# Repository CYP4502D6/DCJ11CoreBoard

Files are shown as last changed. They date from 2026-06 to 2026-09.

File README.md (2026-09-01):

# DEC DCJ-11 PDP-11 Replication Project

Hardware specification and implementation status for the validated v1.3 hardware revision.

## Hardware Specifications 

* **CPU:** DEC DCJ-11
* **FPGA:** Intel/Altera Cyclone IV EP4CE15F23C8N
* **SRAM:** 2× Cypress Semiconductor CY62167EV30LL-45/55ZXI
* **FPGA Configuration Flash:** Winbond W25Q64JVSSIQ
* **UART Interface:** WCH CH340N
* **Bus Transceivers:** 5× Texas Instruments SN74CB3T3245
* **LED Controllers:** 2× Awinic AW21024
* **Status Indicators:** 
    * 8× Onboard direct LEDs (RUN, HALT, ABORT, FETCH, READ, WRITE, IO_SPACE)
    * 16-bit Data bus and 22-bit Address bus LEDs (Driven via AW21024 controllers)
* **MCU & Ethernet Subsystem for DEQNA (v1.3 Integrated):**
    * RP2040 MCU
    * Reserved expansion header for Wiznet W5500 SPI Ethernet PHY module
---

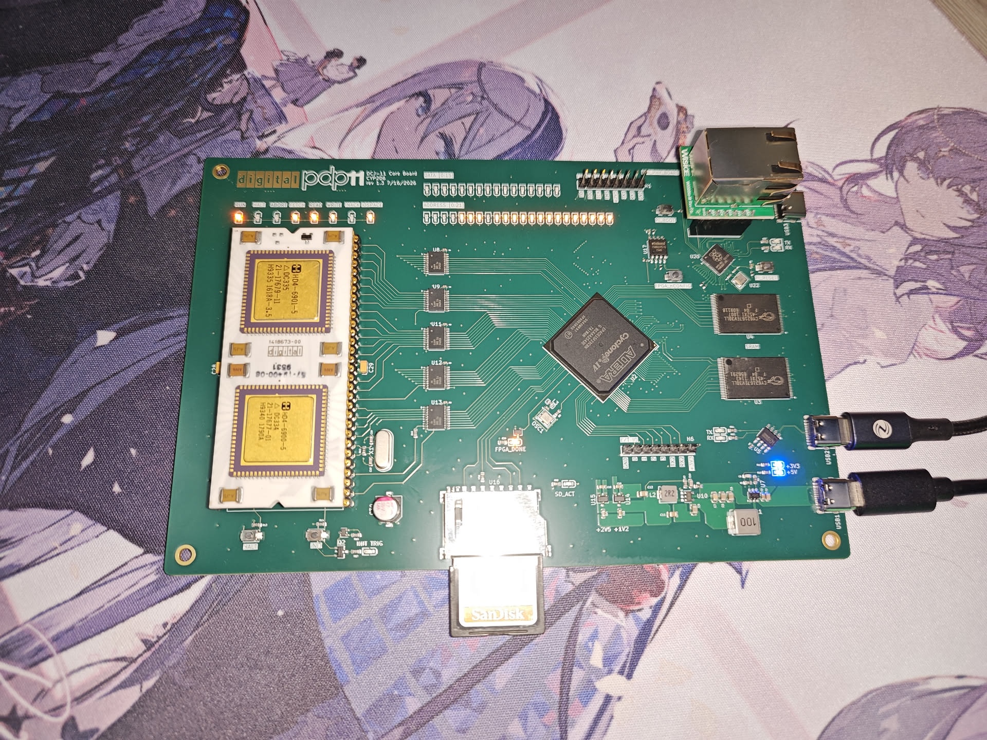
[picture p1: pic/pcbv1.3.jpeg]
Assembled PCB v1.3


## Implementation and Validation Status

### Full 2.11 BSD Unix Implementation for v1.3 Board
System intergration for running full multi-user mode 2.11 BSD Unix via RP06 disk.
* **Functionality:**
  * Power-on configuration and pre-loading 45Boot bootloader into SRAM starting at octal address `2000`.
  * Full 4 MiB physical SRAM memory mapping exploiting the 22-bit address space.
  * DEC KL11 compatible UART console interface for system terminal I/O.
  * DEC KW11 line-frequency real-time clock generator.
  * DMA-capable DEC RH11 disk controller emulation, enabling direct block transfers for 2.11 BSD RP06 disk images.
* **Resources & Demonstration:**
  * Video Demonstration: https://www.bilibili.com/video/BV1oagP6AEpL/

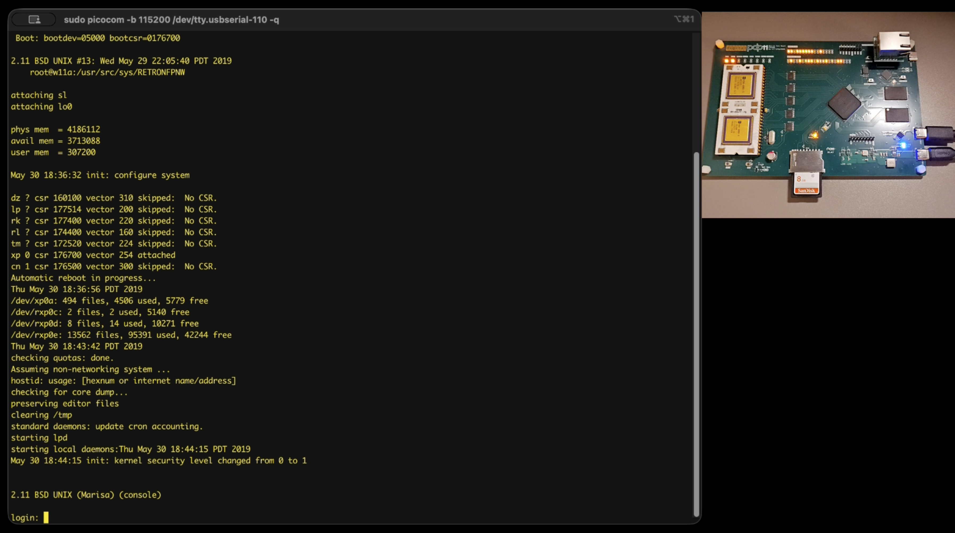
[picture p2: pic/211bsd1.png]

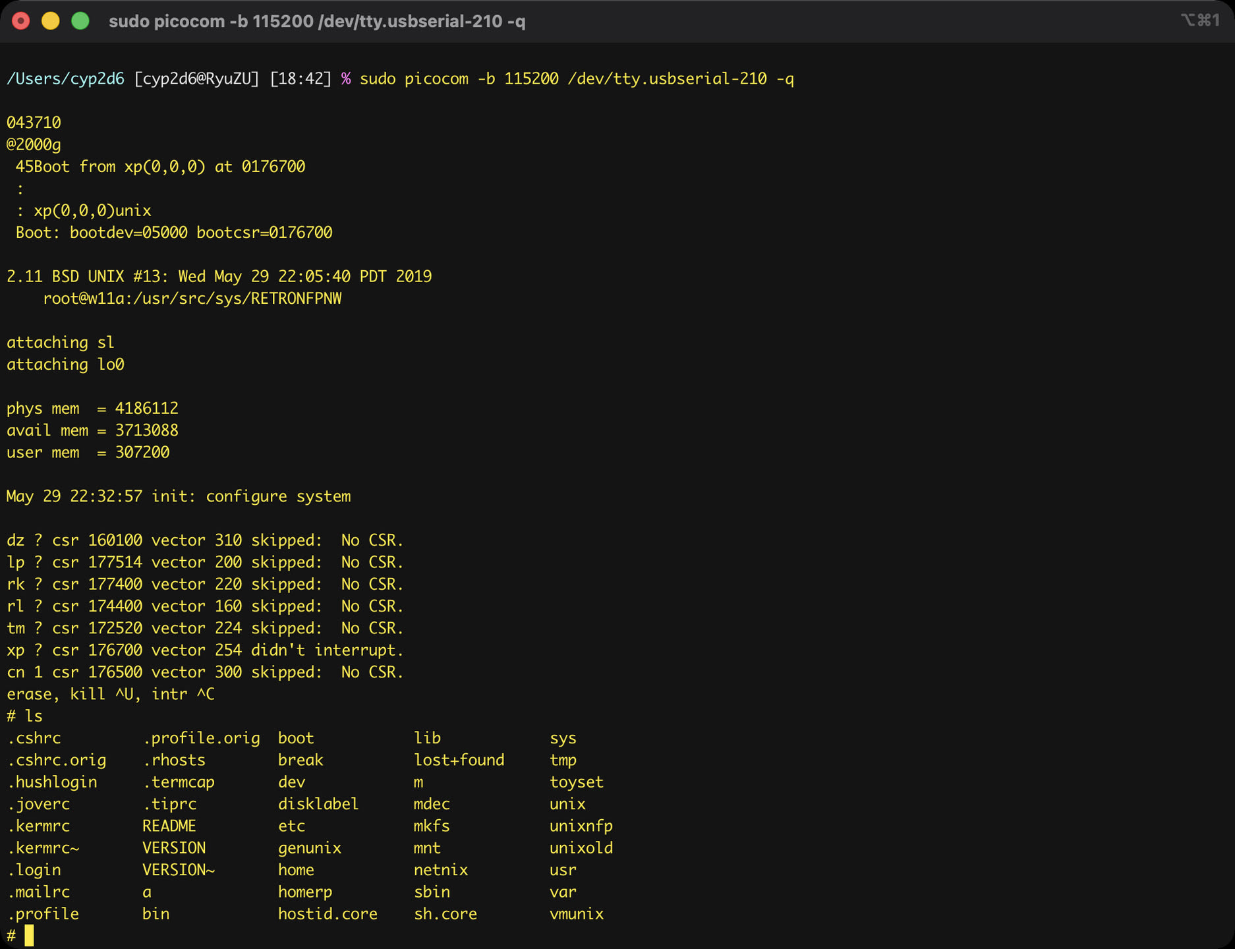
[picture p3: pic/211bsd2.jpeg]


### Board-Level Hardware Bringup for v1.2 Board
Initial board-level hardware verification using Verilog to validate subsystem integrity.
* **Scope:** Individual validation of AW21024 controllers, SRAM interface, onboard status LEDs, and UART peripheral lines.

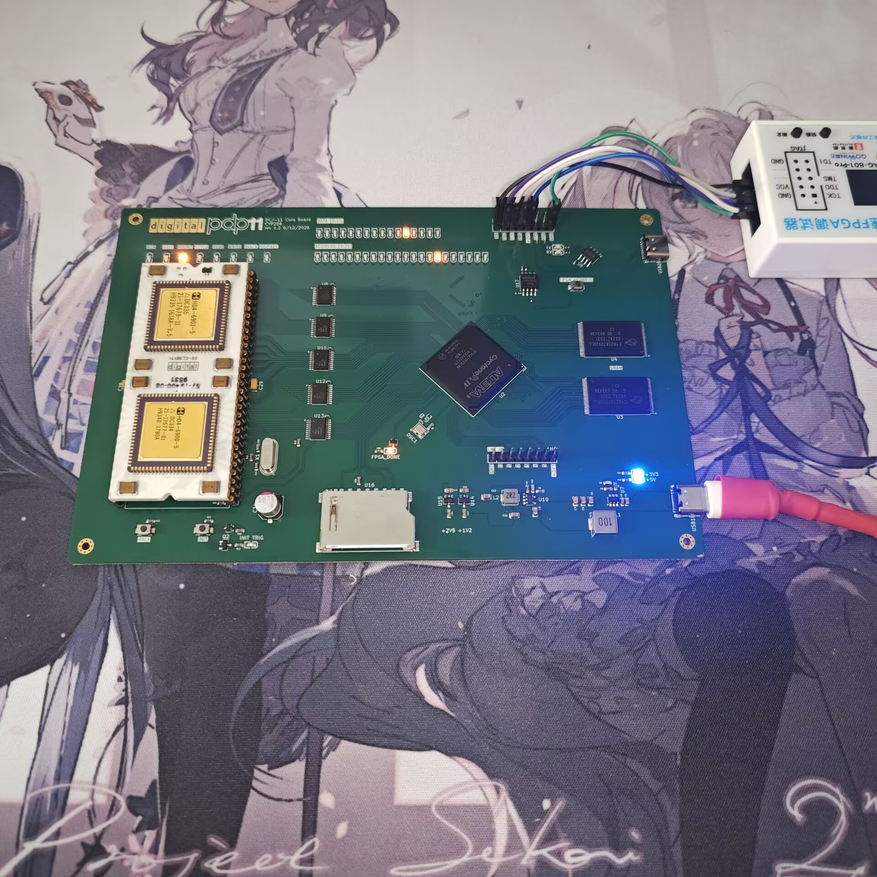
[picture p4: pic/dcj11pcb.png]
Board Top

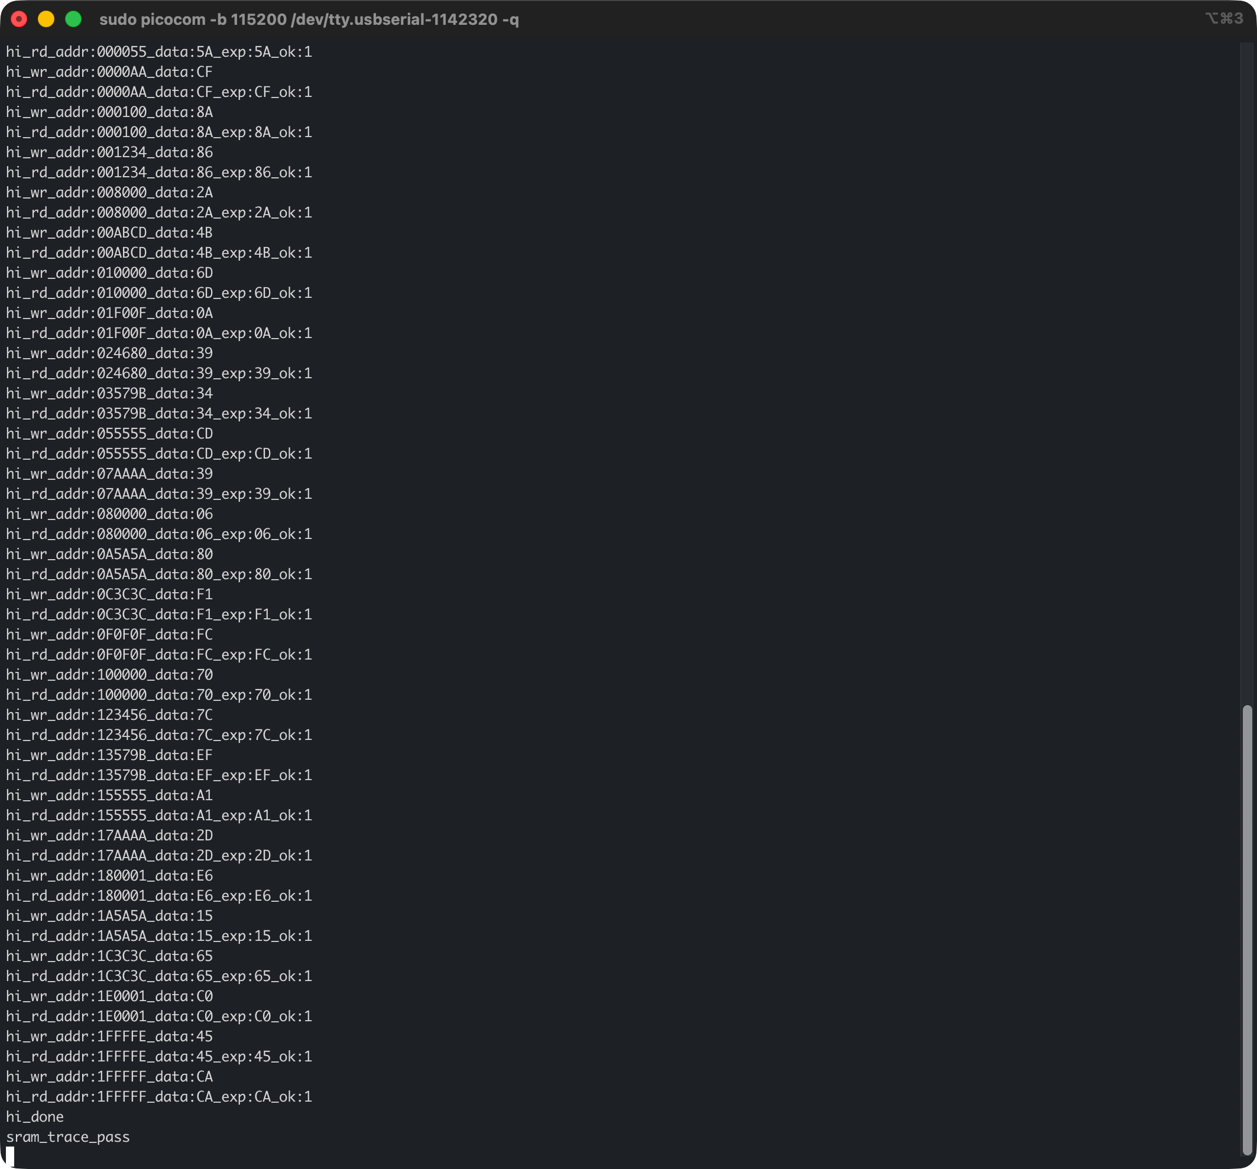
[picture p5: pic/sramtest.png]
SRAM Test Output

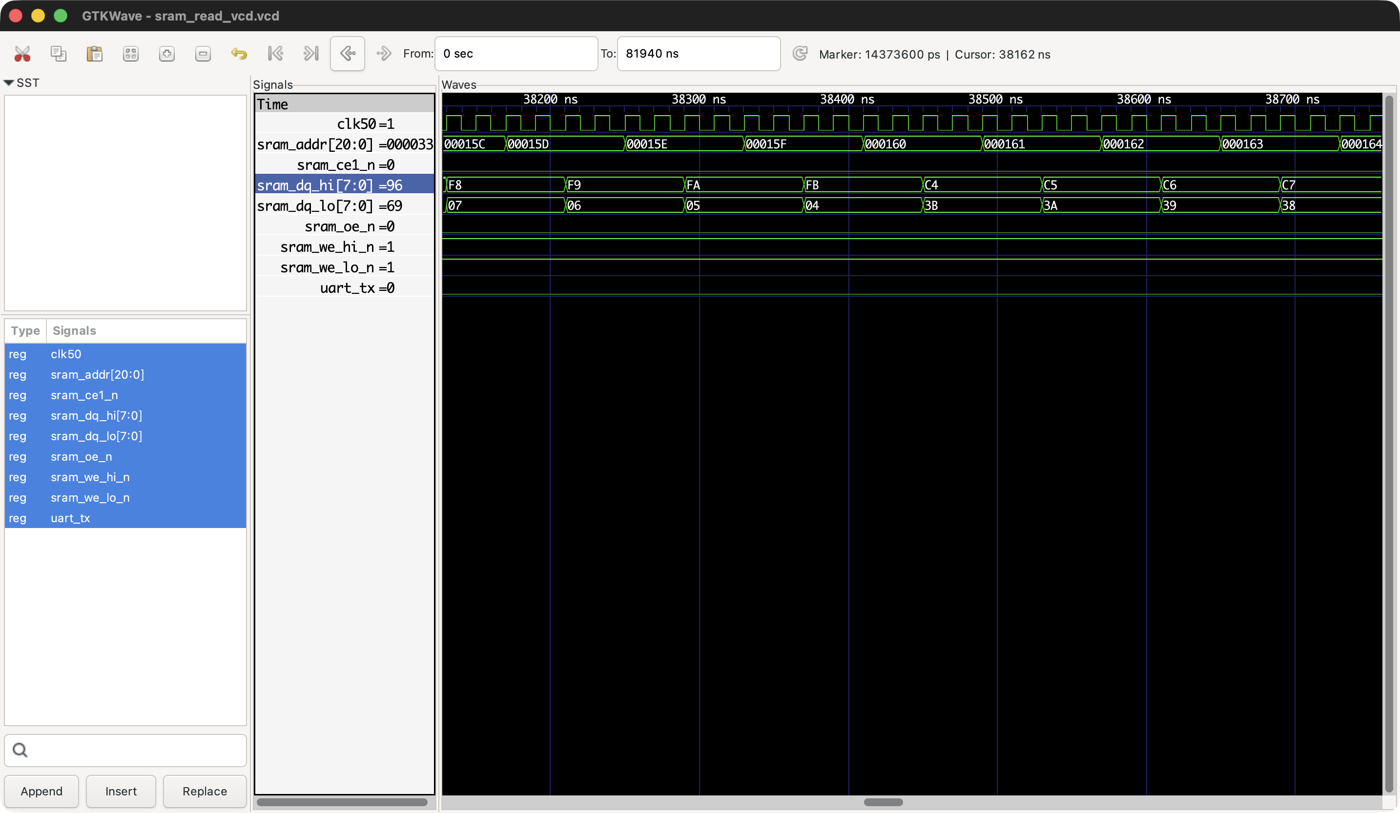
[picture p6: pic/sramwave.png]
SRAM Signal Waveform


### Full System Integration (Hello World Project) for v1.2 Board
System-level integration project executing on the DCJ-11 CPU.
* **Functionality:** 
    * Power-on configuration initialization to enter Console ODT mode.
    * 2 KB (1 Kword) active SRAM memory mapping.
    * DEC KL11 compatible UART console interface configuration.
    * Dynamic bus status and address/data line LED mapping.
    * Pre-loaded execution code within SRAM executing a string print operation to the UART console.

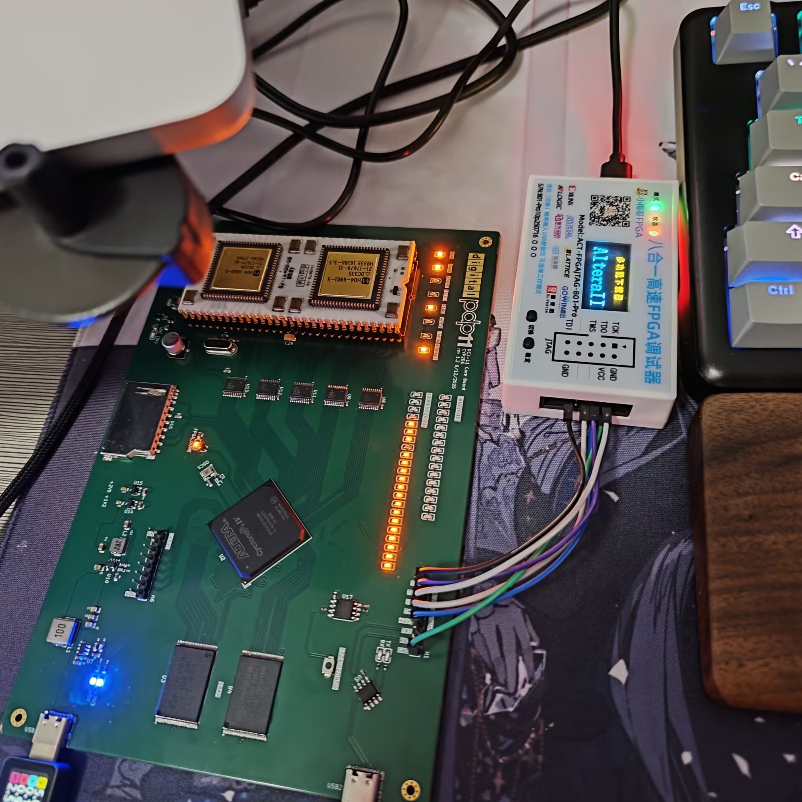
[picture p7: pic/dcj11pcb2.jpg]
Assembled Board v1.2

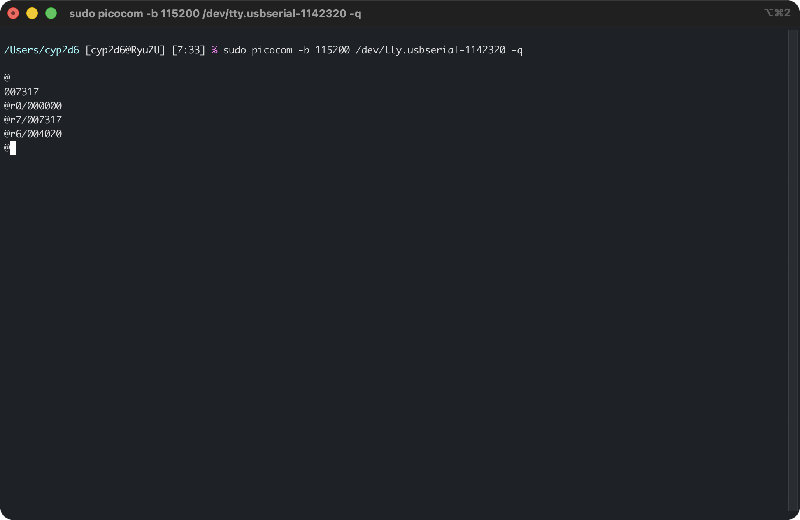
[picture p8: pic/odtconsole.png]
Console ODT Terminal

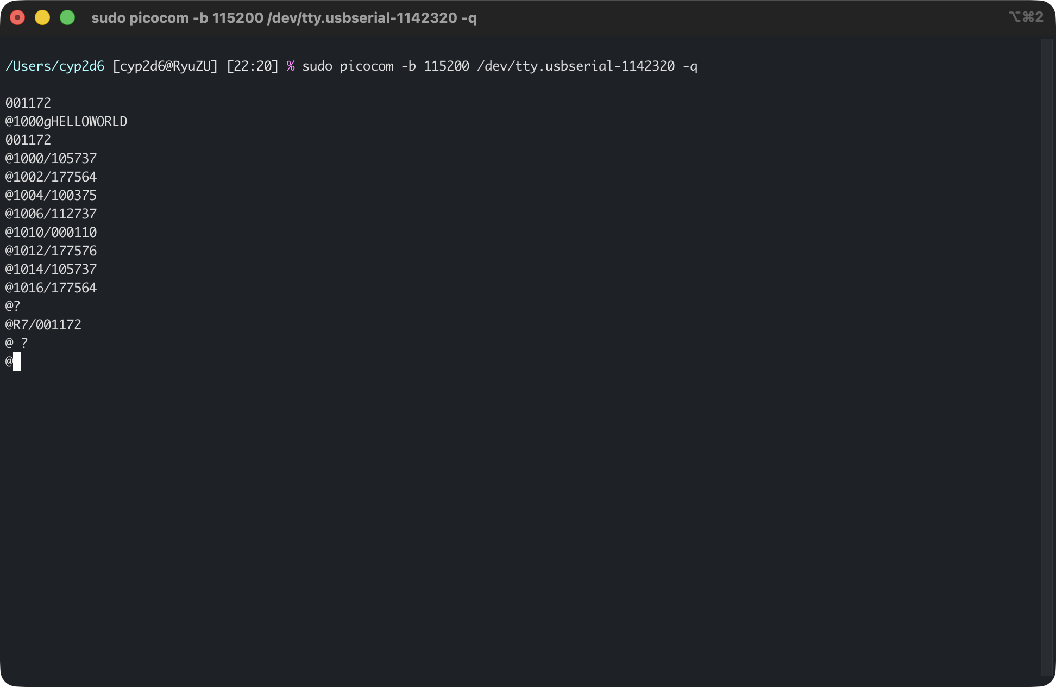
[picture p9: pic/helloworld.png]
Hello World Output


### TapeBASIC Implementation
System integration project allowing the execution of PDP-11 Tape BASIC V007A.
* **Functionality:** 
  * Power-on configuration initialization to enter Console ODT mode.
  * 64 KB address space mapping, allocating 56 KB as active program memory and 8 KB as standard I/O space.
  * DEC KL11 compatible UART console connection.
  * DEC PC11 paper tape reader/punch controller emulation.
  * Dynamic bus status and address/data line LED mapping.
  * SD card sub-system emulating paper tape storage with dual-slot allocation:
    * *System Slot (Read-Only):* Houses the BASIC bootloader and core system image. Automatically switches context post-boot.
    * *User Slot (Read/Write):* Allocated for BASIC user programs and data storage.
* **Usage:** 
  * Data synchronization and partition management within the user slot are handled via provided Python utilities located in the `tools` directory.
  * Pre-compiled configuration bitstream available as `output_file_flash.jic` for direct deployment to the FPGA configuration flash via an external programmer.

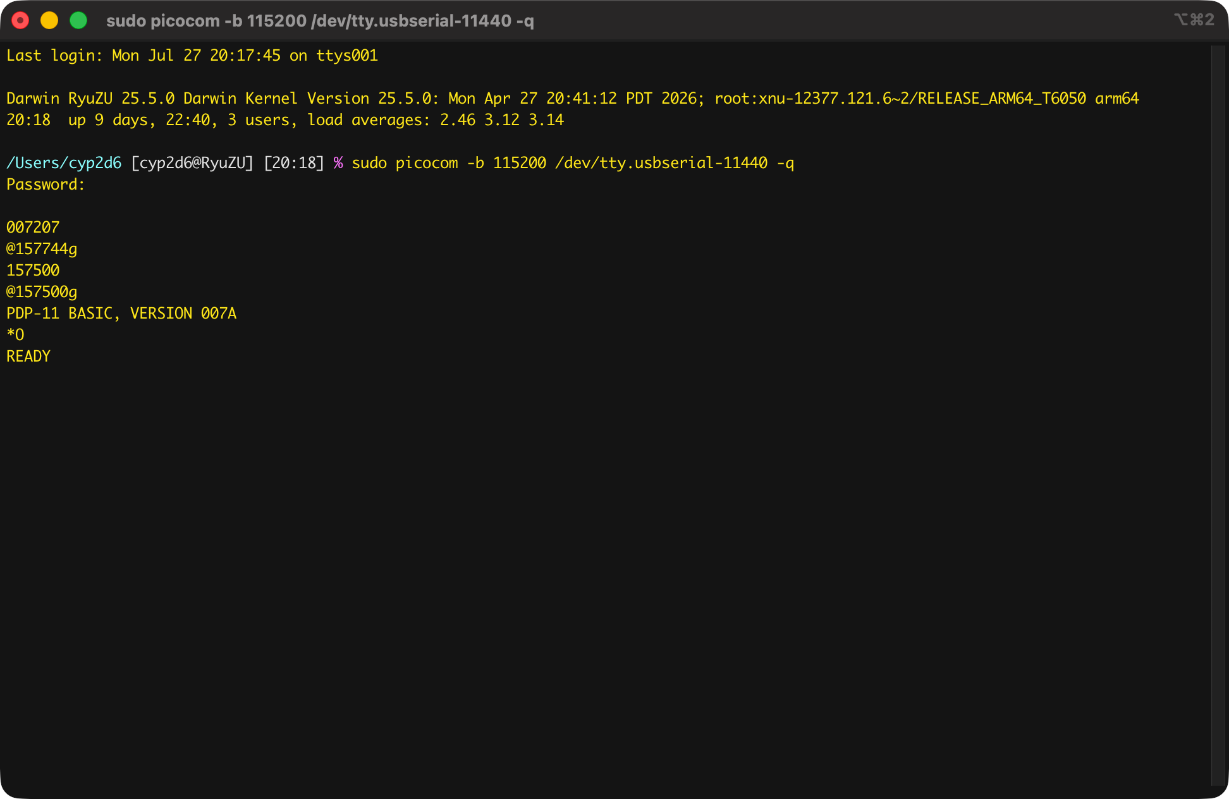
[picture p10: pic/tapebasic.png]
Tape BASIC for v1.3 Board


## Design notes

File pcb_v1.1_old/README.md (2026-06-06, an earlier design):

# PDP-11 Single-Board-Computer Replication Project

Temporary specification sheet for the DEC DCJ-11 and FPGA-based PDP-11 replication hardware. Using FPGA as a bus controller and emulating peripherals such as disk drives.

## Core Hardware (v1.0 - v1.1)
* **CPU:** DEC DCJ-11
* **FPGA:** Gowin GW1N-LV9LQ144
* **SRAM:** 2× CY62167EV30LL
* **Bus voltage conversion:** 5× SN74CB3T3245PWR

---

## Hardware Revisions

### v1.0 (Fabricated)
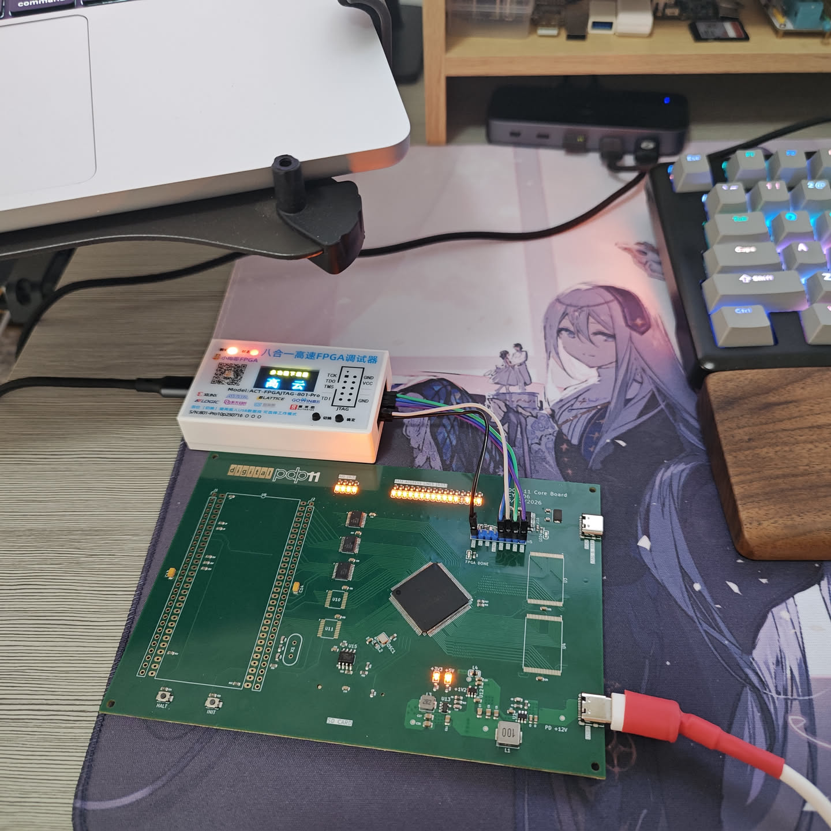
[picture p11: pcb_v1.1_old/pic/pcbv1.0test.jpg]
v1.0 Board


**Known Issues:**
* CH221K (USB PD): Missing series resistors on power lines.
* SD Slot: VCC and GND pins are inverted.
* CH347: Incompatible as a Gowin JTAG debugger.
* The absence of balanced copper on the top and bottom layers caused thermal expansion and contraction issues during SMT production.

### v1.1 (Unfabricated)
* Errata from v1.0 fixed in design files. Production bypassed.

### v1.2 (In Development)
* **Architecture Change:** Migrating to Altera Cyclone IV EP4CE15F23 and Raspberry Pi RP2040. Integrating original PDP-11 front panel status indicators.

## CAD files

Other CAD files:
dcj11_helloworld/task7_sram_2kb_hello/stp1.stp
dcj11_tapebasic/stp1.stp
dcj11_unixbus/stp2.stp

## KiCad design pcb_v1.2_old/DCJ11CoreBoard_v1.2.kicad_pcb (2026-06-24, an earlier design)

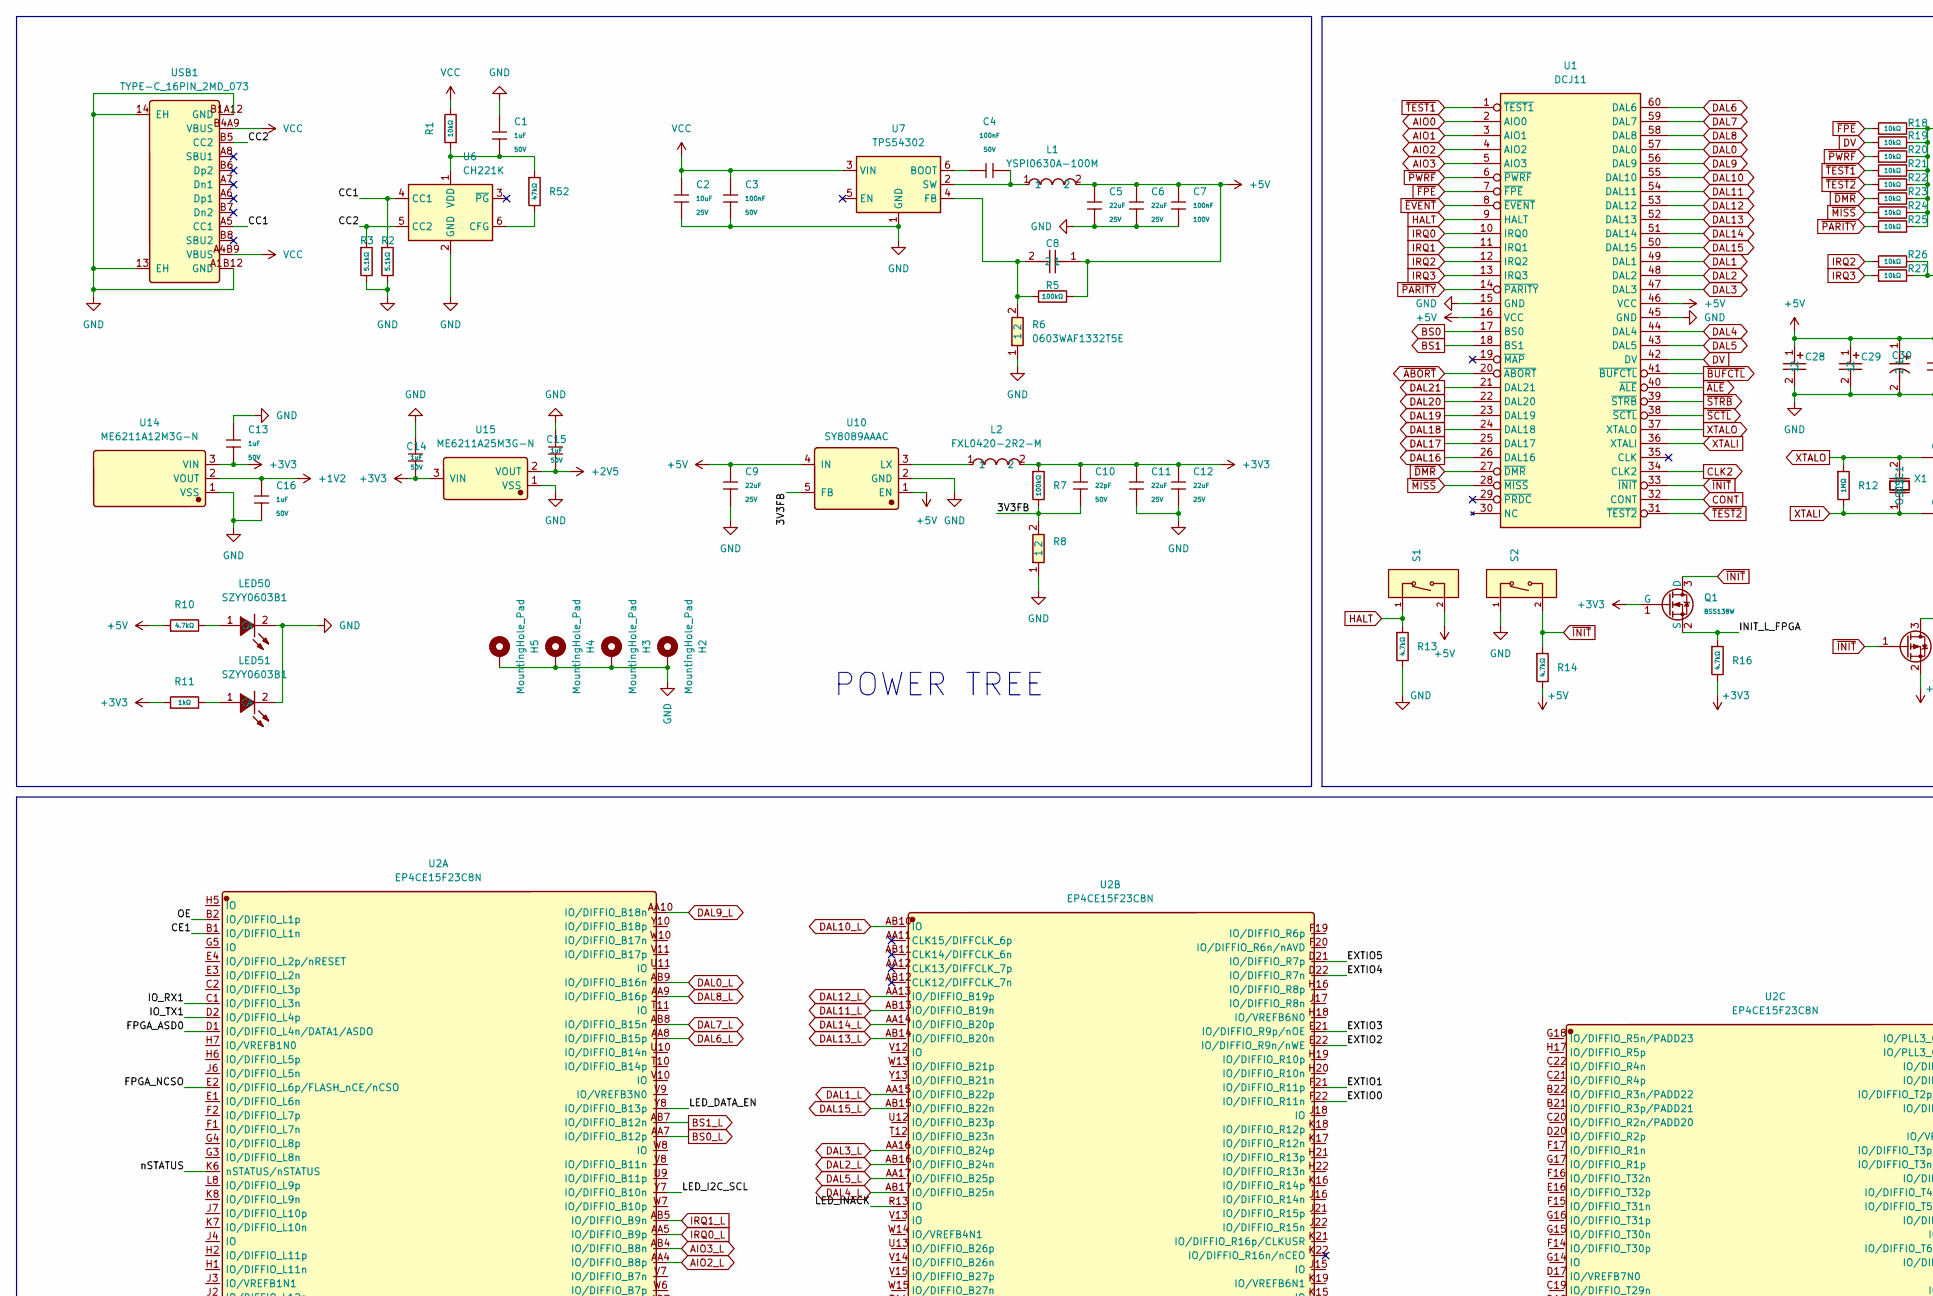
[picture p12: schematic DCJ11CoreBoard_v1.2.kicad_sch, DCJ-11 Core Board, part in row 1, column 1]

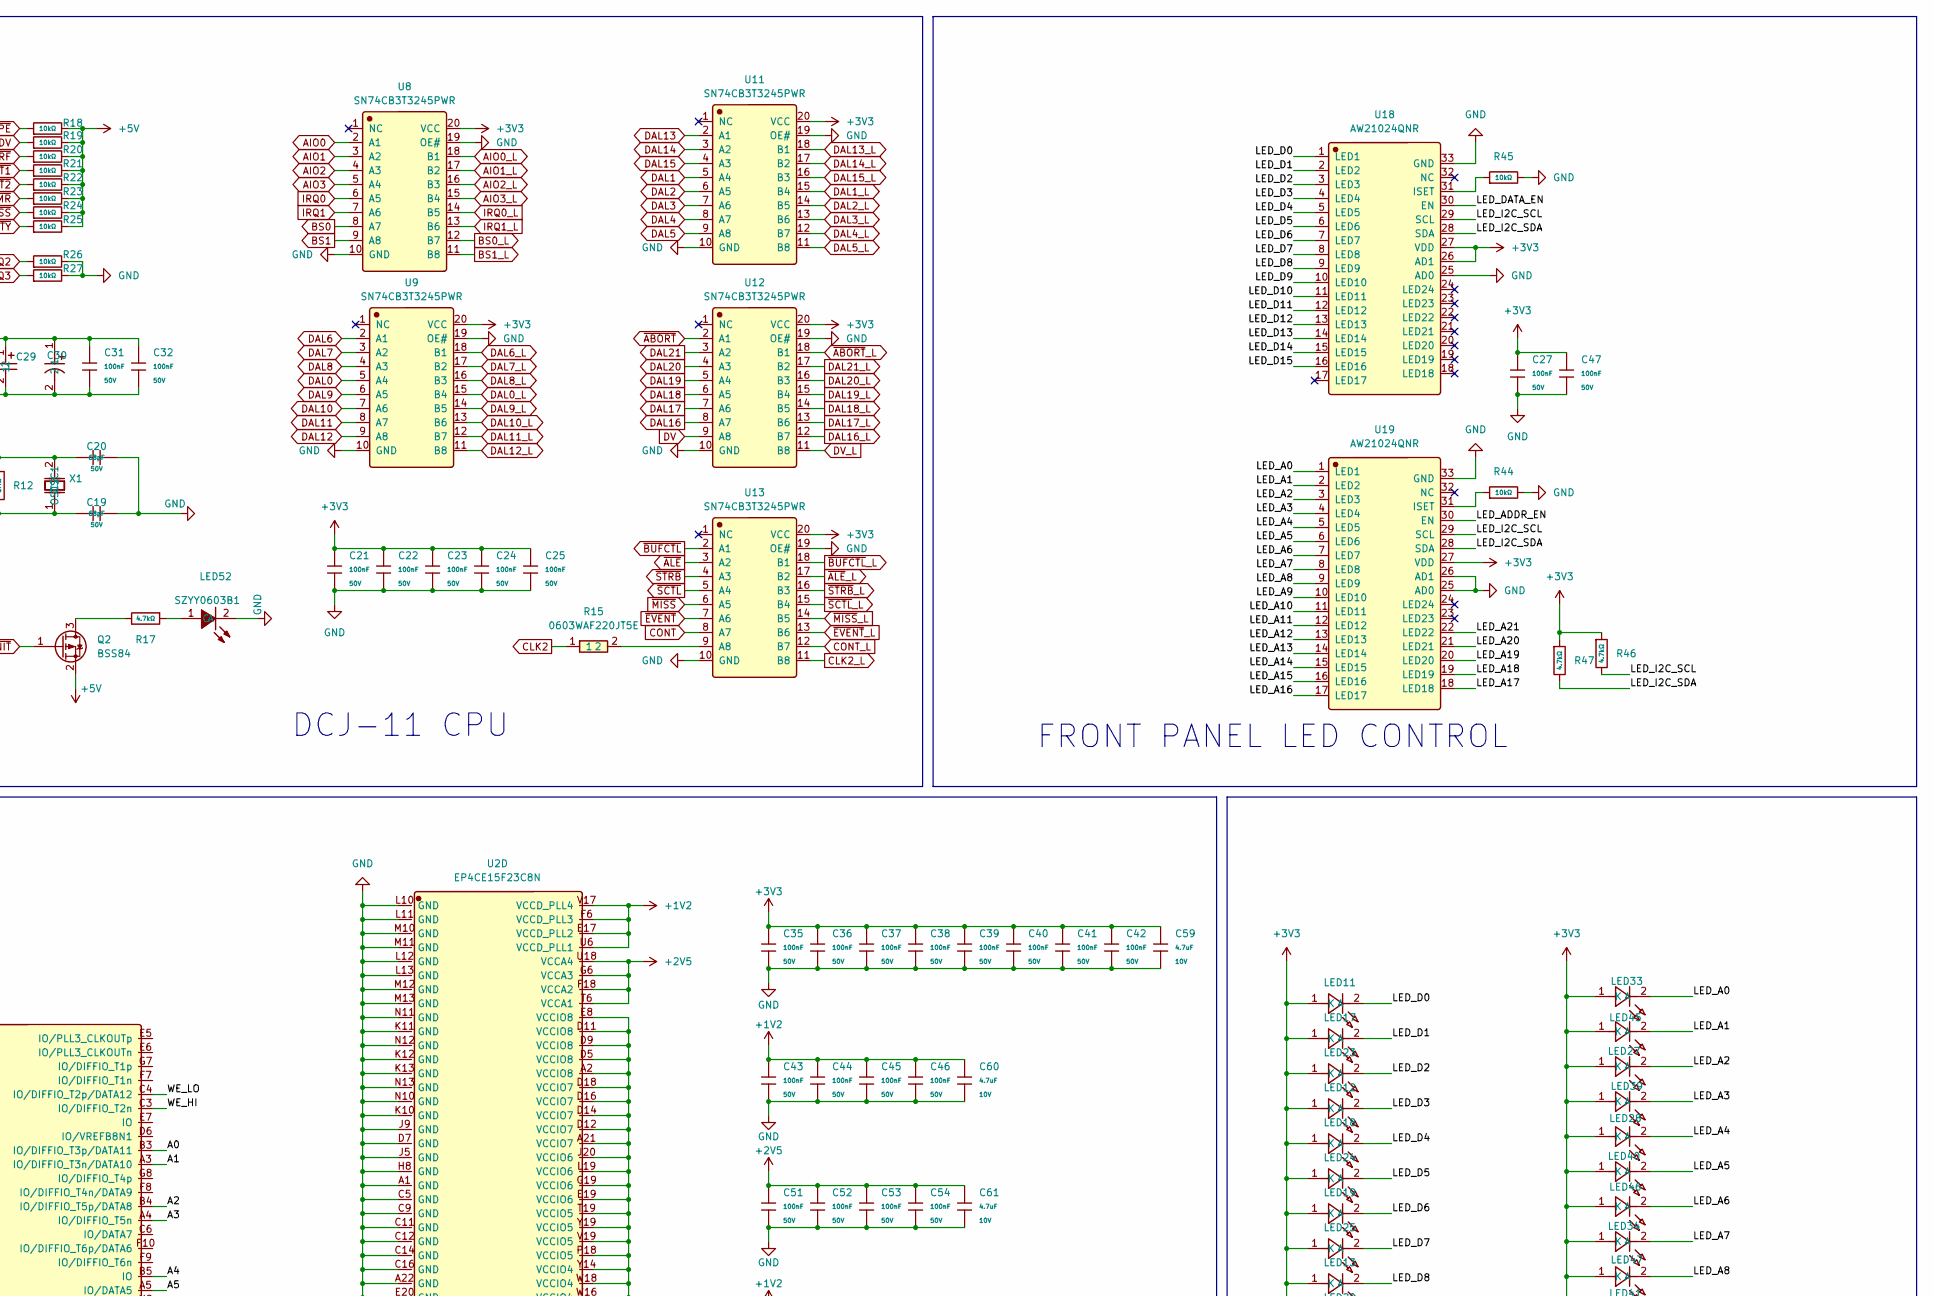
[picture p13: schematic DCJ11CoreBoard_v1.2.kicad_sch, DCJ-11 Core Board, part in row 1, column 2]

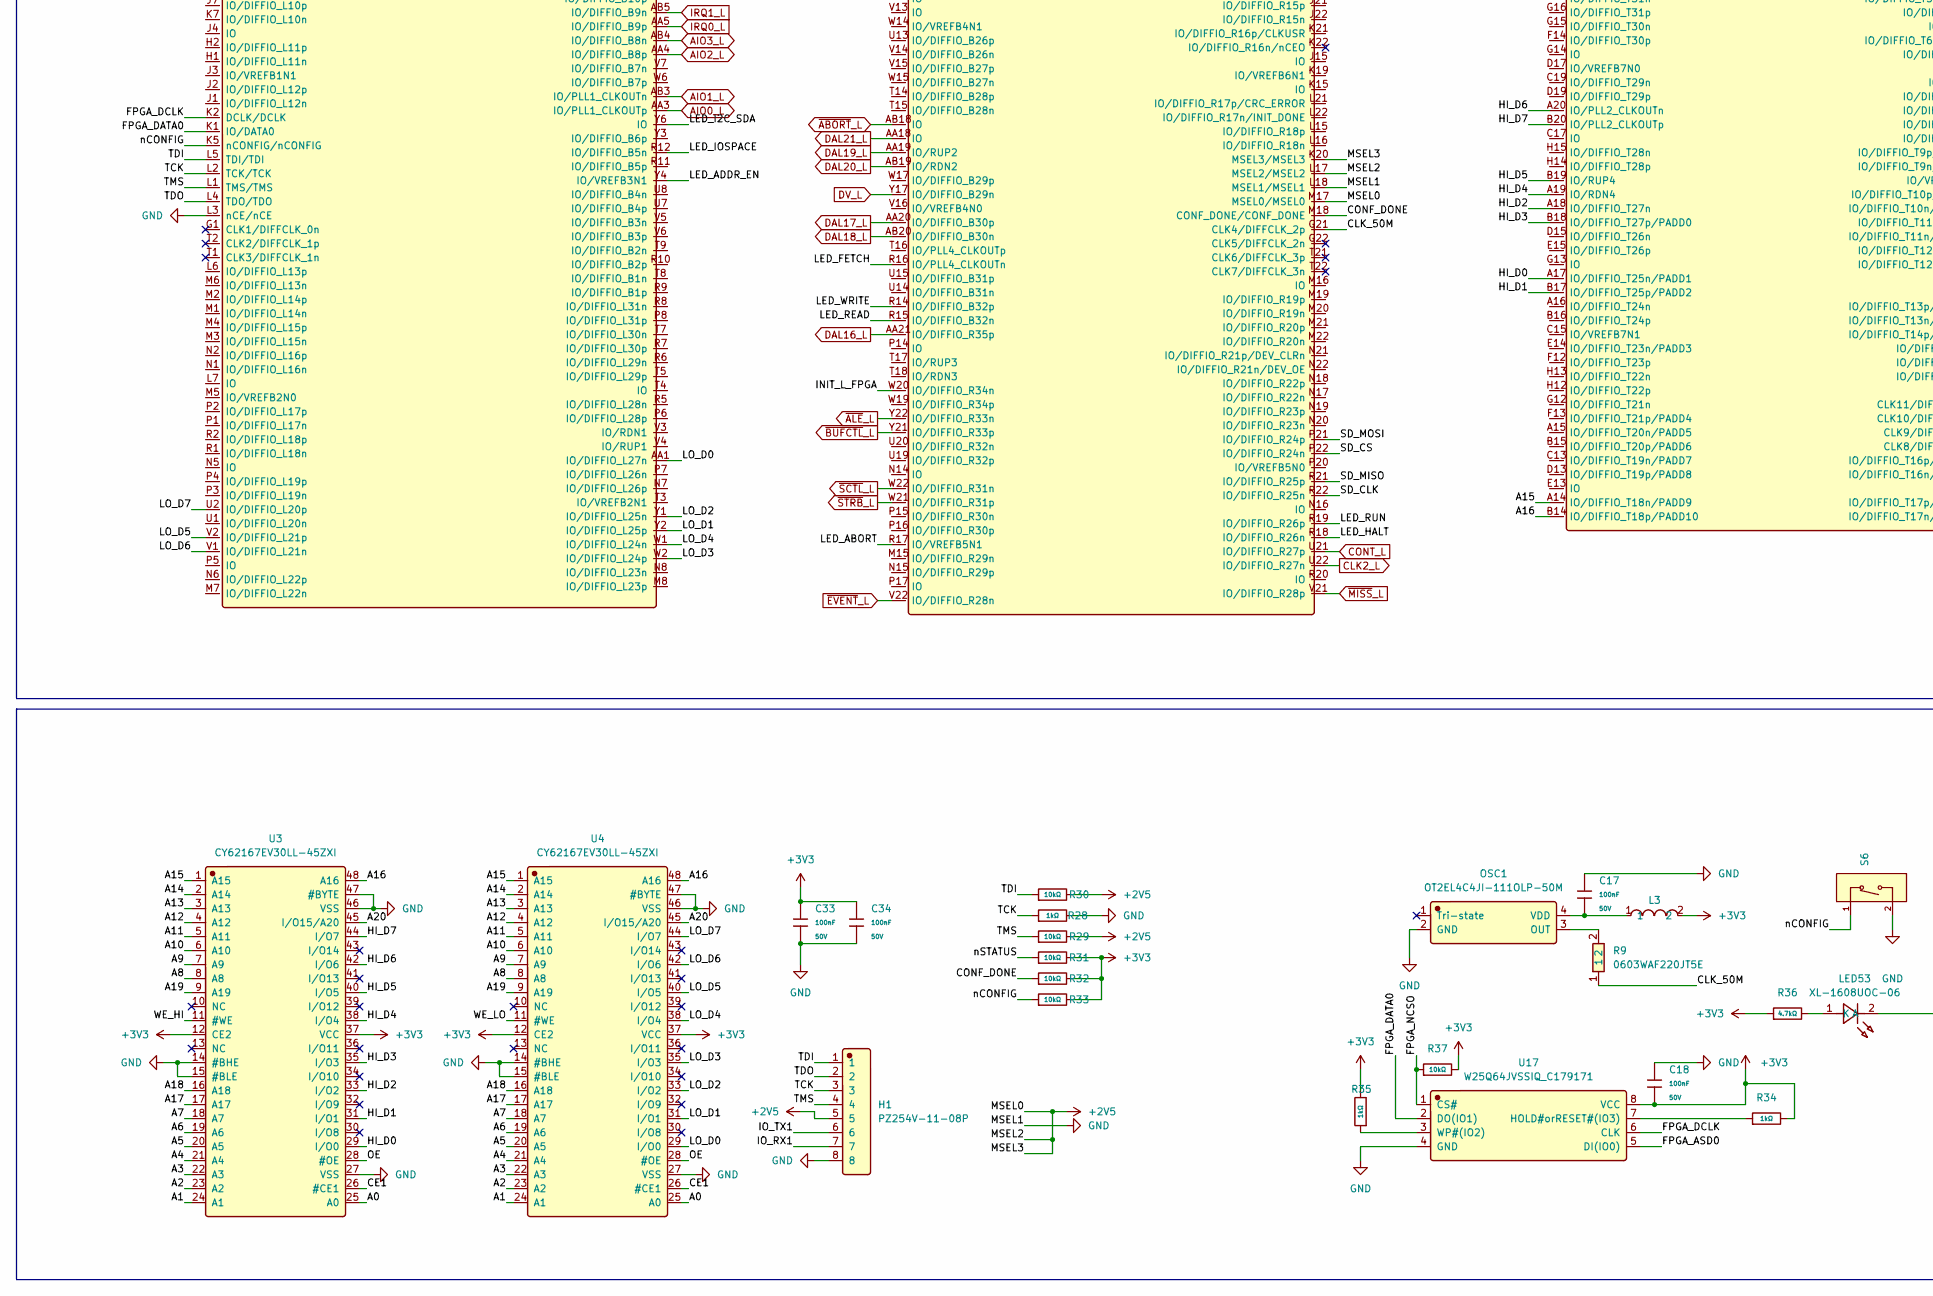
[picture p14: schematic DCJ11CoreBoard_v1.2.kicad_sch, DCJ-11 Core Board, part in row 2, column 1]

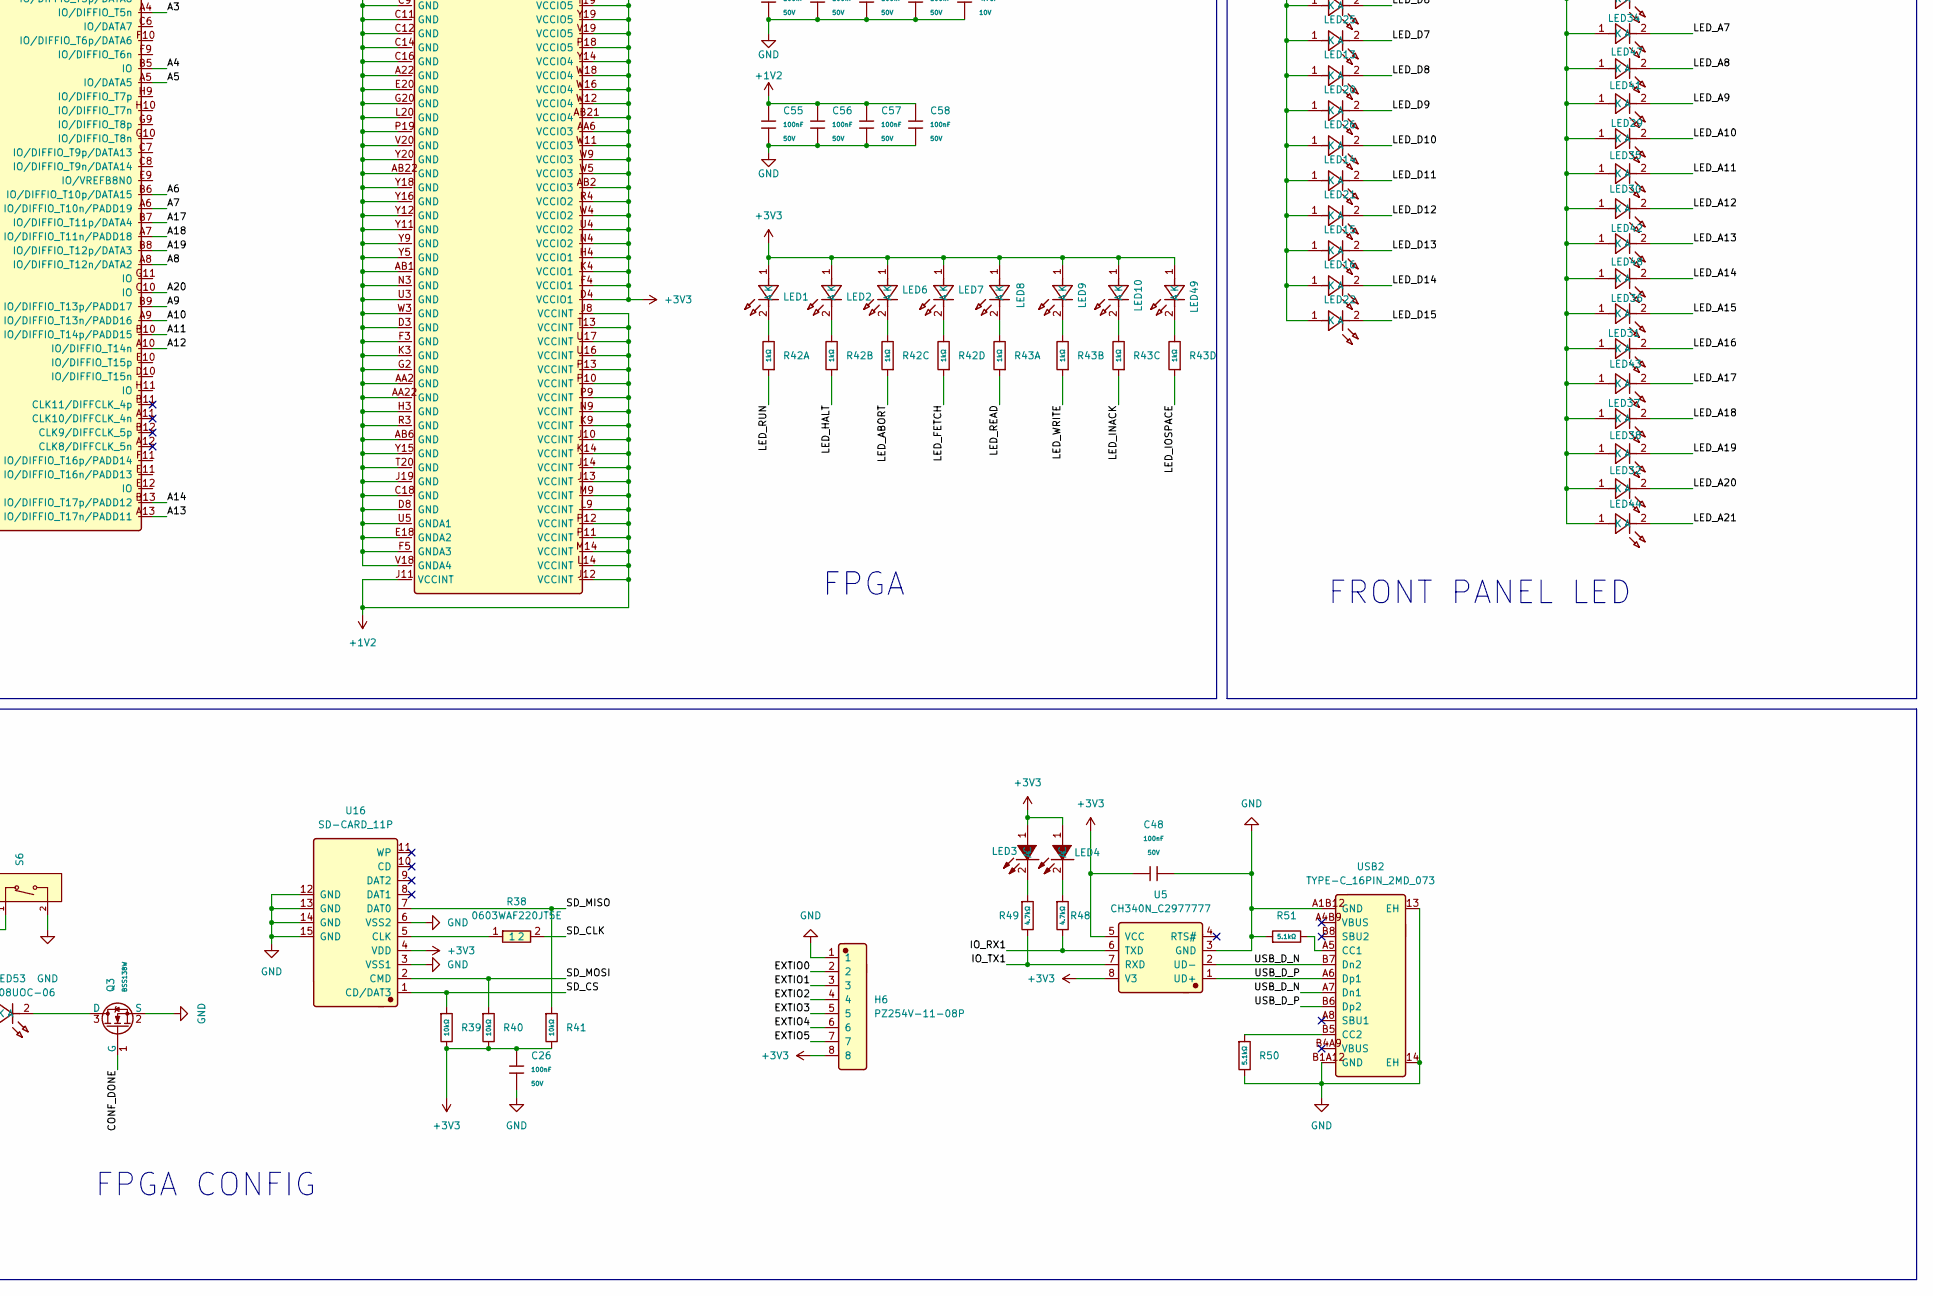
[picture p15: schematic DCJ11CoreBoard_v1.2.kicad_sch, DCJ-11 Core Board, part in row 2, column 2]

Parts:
C1, C13, C14, C15, C16: 1uF; C_0603; Voltage Rated 50V; Tolerance ±10%; Part CL10A105KB8NNNC; LCSC C15849
C2: 10uF; C_0603; Voltage Rated 25V; Tolerance ±20%; Part CL10A106MA8NRNC; LCSC C96446
C3: 100nF; C_0603; Voltage Rated 50V; Tolerance ±10%; Part CC0603KRX7R9BB104; LCSC C14663
C4, C17, C18, C21, C22, C23, C24, C25, C26, C27, C31, C32, C33, C34, C35, C36, C37, C38, C39, C40, C41, C42, C43, C44, C45, C46, C47, C48, C51, C52, C53, C54, C55, C56, C57, C58: 100nF; C_0402; Voltage Rated 50V; Tolerance ±10%; Part CL05B104KB54PNC; LCSC C307331
C5, C6, C9, C11, C12: 22uF; C_0805; Voltage Rated 25V; Tolerance ±20%; Part CL21A226MAQNNNE; LCSC C45783
C7: 100nF; C_0805; Voltage Rated 100V; Tolerance ±10%; Part CL21B104KCFNNNE; LCSC C28233
C8: CC0603JRNPO9BN750; C_0603; Manufacturer Part CC0603JRNPO9BN750; LCSC C282074
C10: 22pF; C_0603; Voltage Rated 50V; Tolerance ±5%; Part CL10C220JB8NNNC; LCSC C1653
C19, C20: 68pF; C_0603; Voltage Rated 50V; Tolerance ±5%; Part CL10C680JB8NNNC; LCSC C28262
C28, C29: TAJA334K035RNJ; Manufacturer Part TAJA334K035RNJ; LCSC C8014
C30: MA35V47M6X6; Manufacturer Part MA35V47M6X6; LCSC C46550468
C59, C60, C61: 4.7uF; C_0402; Voltage Rated 10V; Tolerance ±20%; Part CL05A475MP5NRNC; LCSC C23733
H1, H6: PZ254V-11-08P; Manufacturer Part PZ254V-11-08P; LCSC C492407
H2, H3, H4, H5: MountingHole_Pad; MountingHole_2.2mm_M2_Pad_Via
L1: YSPI0630A-100M; Manufacturer Part YSPI0630A-100M; LCSC C497871
L2: FXL0420-2R2-M; Manufacturer Part FXL0420-2R2-M; LCSC C167206
L3: BLM18AG601SN1D; Manufacturer Part BLM18AG601SN1D; LCSC C19330
LED1, LED2, LED6, LED7, LED8, LED9, LED10, LED11, LED12, LED13, LED14, LED15, LED16, LED17, LED18, LED19, LED20, LED21, LED22, LED23, LED24, LED25, LED26, LED27, LED28, LED29, LED30, LED31, LED32, LED33, LED34, LED35, LED36, LED37, LED38, LED39, LED40, LED41, LED42, LED43, LED44, LED45, LED46, LED47, LED48, LED49, LED53: XL-1608UOC-06; Manufacturer Part XL-1608UOC-06; LCSC C965800
LED3, LED4, LED50, LED51, LED52: SZYY0603B1; Manufacturer Part SZYY0603B1; LCSC C19712531
OSC1: OT2EL4C4JI-111OLP-50M; Manufacturer Part OT2EL4C4JI-111OLP-50M; LCSC C5203552
Q1, Q3: BSS138W; Q_SOT-323; Part BSS138W; LCSC C28646265
Q2: BSS84; SOT-23
R1, R18, R19, R20, R21, R22, R23, R24, R25, R26, R27: 10kΩ; R_0603; Overload Voltage (Max) 75V; Tolerance ±1%; Part 0603WAF1002T5E; LCSC C25804
R2, R3, R50, R51: 5.1kΩ; R_0603; Overload Voltage (Max) 75V; Tolerance ±1%; Part 0603WAF5101T5E; LCSC C23186
R5, R7: 100kΩ; R_0603; Overload Voltage (Max) 75V; Tolerance ±1%; Part 0603WAF1003T5E; LCSC C25803
R6: 0603WAF1332T5E; R_0603; Manufacturer Part 0603WAF1332T5E; LCSC C25952
R8: 0603WAF2212T5E; R_0603; Manufacturer Part 0603WAF2212T5E; LCSC C25961
R9, R15, R38: 0603WAF220JT5E; R_0603; Manufacturer Part 0603WAF220JT5E; LCSC C23345
R10, R13, R14, R16, R17, R36: 4.7kΩ; R_0603; Overload Voltage (Max) 75V; Tolerance ±1%; Part 0603WAF4701T5E; LCSC C23162
R11: 1kΩ; R_0603; Overload Voltage (Max) 75V; Tolerance ±1%; Part 0603WAF1001T5E; LCSC C21190
R12: 1MΩ; R_0603; Overload Voltage (Max) 75V; Tolerance ±1%; Part 0603WAF1004T5E; LCSC C22935
R28, R34, R35: 1kΩ; R_0402; Overload Voltage (Max) 50V; Tolerance ±1%; Part 0402WGF1001TCE; LCSC C11702
R29, R30, R31, R32, R33, R37, R39, R40, R41, R44, R45: 10kΩ; R_0402; Overload Voltage (Max) 50V; Tolerance ±1%; Part 0402WGF1002TCE; LCSC C25744
R42, R43: 1kΩ; R_0603x4; Tolerance ±5%; Part 4D03WGJ0102T5E; LCSC C20197
R46, R47, R48, R49: 4.7kΩ; R_0402; Overload Voltage (Max) 50V; Tolerance ±1%; Part 0402WGF4701TCE; LCSC C25900
R52: 47kΩ; R_0402; Overload Voltage (Max) 50V; Tolerance ±1%; Part 0402WGF4702TCE; LCSC C25792
S1, S2, S6: Tactile Button, 160gf; SW_TS-1088-AR02016; Voltage Rating (Dc) 12V; Part TS-1088-AR02016; LCSC C720477
U1: DCJ11; DIP-60_W33.02mm_LongPads
U2: EP4CE15F23C8N; Manufacturer Part EP4CE15F23C8N; LCSC C695265
U3, U4: CY62167EV30LL-45ZXI; TSOP-I-48_18.4x12mm_P0.5mm; Manufacturer Part CY62167EV30LL-45ZXI; LCSC C115715
U5: CH340N_C2977777; Manufacturer Part CH340N; LCSC C2977777
U6: CH221K; SOT-23-6
U7: TPS54302; SOT-23-6
U8, U9, U11, U12, U13: SN74CB3T3245PWR; TSSOP-20_4.4x6.5mm_P0.65mm; Manufacturer Part SN74CB3T3245PWR; LCSC C15298
U10: SY8089AAAC; SOT-23-5; Manufacturer Part SY8089AAAC; LCSC C78988
U14: ME6211A12M3G-N; SOT-23-3; Manufacturer Part ME6211A12M3G-N; LCSC C236678
U15: ME6211A25M3G-N; SOT-23-3; Manufacturer Part ME6211A25M3G-N; LCSC C2835782
U16: SD-CARD_11P; Manufacturer Part SD-CARD 11P; LCSC C7529393
U17: W25Q64JVSSIQ_C179171; SOIC-8_5.3x5.3mm_P1.27mm; Manufacturer Part W25Q64JVSSIQ; LCSC C179171
U18, U19: AW21024QNR; Manufacturer Part AW21024QNR; LCSC C2891574
USB1, USB2: TYPE-C_16PIN_2MD_073; Manufacturer Part TYPE-C 16PIN 2MD(073); LCSC C2765186
X1: 9BC18000151060C3; Manufacturer Part 9BC18000151060C3; LCSC C2715887

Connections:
+1V2: C16.1, C43.1, C44.1, C45.1, C46.1, C55.1, C56.1, C57.1, C58.1, C60.1, U2.E17 (VCCD_PLL2), U2.F6 (VCCD_PLL3), U2.J8 (VCCINT), U2.J10 (VCCINT), U2.J11 (VCCINT), U2.J12 (VCCINT), U2.J13 (VCCINT), U2.J14 (VCCINT), U2.K9 (VCCINT), U2.K14 (VCCINT), U2.L9 (VCCINT), U2.L14 (VCCINT), U2.M9 (VCCINT), U2.M14 (VCCINT), U2.N9 (VCCINT), U2.P9 (VCCINT), U2.P10 (VCCINT), U2.P11 (VCCINT), U2.P12 (VCCINT), U2.P13 (VCCINT), U2.T13 (VCCINT), U2.U6 (VCCD_PLL1), U2.U16 (VCCINT), U2.U17 (VCCINT), U2.V17 (VCCD_PLL4), U14.2 (VOUT)
+2V5: C15.2, C51.1, C52.1, C53.1, C54.1, C61.1, H1.5, R29.2, R30.2, U2.F18 (VCCA2), U2.G6 (VCCA3), U2.K20 (MSEL3/MSEL3), U2.L17 (MSEL2/MSEL2), U2.M17 (MSEL0/MSEL0), U2.T6 (VCCA1), U2.U18 (VCCA4), U15.2 (VOUT)
+3V3: C10.1, C11.1, C12.1, C13.2, C14.2, C18.2, C21.1, C22.1, C23.1, C24.1, C25.1, C26.1, C27.1, C33.1, C34.1, C35.1, C36.1, C37.1, C38.1, C39.1, C40.1, C41.1, C42.1, C47.1, C48.1, C59.1, H6.8, L2.2, L3.2, LED1.1 (K), LED2.1 (K), LED3.1 (A), LED4.1 (A), LED6.1 (K), LED7.1 (K), LED8.1 (K), LED9.1 (K), LED10.1 (K), LED11.1 (K), LED12.1 (K), LED13.1 (K), LED14.1 (K), LED15.1 (K), LED16.1 (K), LED17.1 (K), LED18.1 (K), LED19.1 (K), LED20.1 (K), LED21.1 (K), LED22.1 (K), LED23.1 (K), LED24.1 (K), LED25.1 (K), LED26.1 (K), LED27.1 (K), LED28.1 (K), LED29.1 (K), LED30.1 (K), LED31.1 (K), LED32.1 (K), LED33.1 (K), LED34.1 (K), LED35.1 (K), LED36.1 (K), LED37.1 (K), LED38.1 (K), LED39.1 (K), LED40.1 (K), LED41.1 (K), LED42.1 (K), LED43.1 (K), LED44.1 (K), LED45.1 (K), LED46.1 (K), LED47.1 (K), LED48.1 (K), LED49.1 (K), Q1.1 (G), R7.1, R11.1, R16.2, R31.2, R32.2, R33.2, R34.2, R35.2, R36.1, R37.2, R39.2, R40.2, R41.2, R46.1, R47.1, U2.A2 (VCCIO8), U2.A21 (VCCIO7), U2.AA6 (VCCIO3), U2.AB2 (VCCIO3), U2.AB21 (VCCIO4), U2.D4 (VCCIO1), U2.D5 (VCCIO8), U2.D9 (VCCIO8), U2.D11 (VCCIO8), U2.D12 (VCCIO7), U2.D14 (VCCIO7), U2.D16 (VCCIO7), U2.D18 (VCCIO7), U2.E8 (VCCIO8), U2.E19 (VCCIO6), U2.F4 (VCCIO1), U2.G19 (VCCIO6), U2.H4 (VCCIO1), U2.J20 (VCCIO6), U2.K4 (VCCIO1), U2.L19 (VCCIO6), U2.N4 (VCCIO2), U2.P18 (VCCIO5), U2.R4 (VCCIO2), U2.T19 (VCCIO5), U2.U4 (VCCIO2), U2.V19 (VCCIO5), U2.W4 (VCCIO2), U2.W5 (VCCIO3), U2.W9 (VCCIO3), U2.W11 (VCCIO3), U2.W12 (VCCIO4), U2.W16 (VCCIO4), U2.W18 (VCCIO4), U2.Y14 (VCCIO4), U2.Y19 (VCCIO5), U3.12 (CE2), U3.37 (VCC), U4.12 (CE2), U4.37 (VCC), U5.5 (VCC), U5.8 (V3), U8.20 (VCC), U9.20 (VCC), U11.20 (VCC), U12.20 (VCC), U13.20 (VCC), U14.3 (VIN), U15.3 (VIN), U16.4 (VDD), U17.8 (VCC), U18.26 (AD1), U18.27 (VDD), U19.27 (VDD)
+5V: C5.1, C6.1, C7.1, C8.1, C9.1, C28.1, C29.1, C30.1, C31.1, C32.1, L1.2, Q2.2 (S), R5.2, R10.1, R14.2, R18.2, R19.2, R20.2, R21.2, R22.2, R23.2, R24.2, R25.2, S1.2 (B), U1.16 (VCC), U1.46 (VCC), U10.1 (EN), U10.4 (IN)
/3V3FB: C10.2, R7.2, R8.2, U10.5 (FB)
/A0: U2.B3 (IO/DIFFIO_T3p/DATA11), U3.25 (A0), U4.25 (A0)
/A1: U2.A3 (IO/DIFFIO_T3n/DATA10), U3.24 (A1), U4.24 (A1)
/A2: U2.B4 (IO/DIFFIO_T5p/DATA8), U3.23 (A2), U4.23 (A2)
/A3: U2.A4 (IO/DIFFIO_T5n), U3.22 (A3), U4.22 (A3)
/A4: U2.B5 (IO), U3.21 (A4), U4.21 (A4)
/A5: U2.A5 (IO/DATA5), U3.20 (A5), U4.20 (A5)
/A6: U2.B6 (IO/DIFFIO_T10p/DATA15), U3.19 (A6), U4.19 (A6)
/A7: U2.A6 (IO/DIFFIO_T10n/PADD19), U3.18 (A7), U4.18 (A7)
/A8: U2.A8 (IO/DIFFIO_T12n/DATA2), U3.8 (A8), U4.8 (A8)
/A9: U2.B9 (IO/DIFFIO_T13p/PADD17), U3.7 (A9), U4.7 (A9)
/A10: U2.A9 (IO/DIFFIO_T13n/PADD16), U3.6 (A10), U4.6 (A10)
/A11: U2.B10 (IO/DIFFIO_T14p/PADD15), U3.5 (A11), U4.5 (A11)
/A12: U2.A10 (IO/DIFFIO_T14n), U3.4 (A12), U4.4 (A12)
/A13: U2.A13 (IO/DIFFIO_T17n/PADD11), U3.3 (A13), U4.3 (A13)
/A14: U2.B13 (IO/DIFFIO_T17p/PADD12), U3.2 (A14), U4.2 (A14)
/A15: U2.A14 (IO/DIFFIO_T18n/PADD9), U3.1 (A15), U4.1 (A15)
/A16: U2.B14 (IO/DIFFIO_T18p/PADD10), U3.48 (A16), U4.48 (A16)
/A17: U2.B7 (IO/DIFFIO_T11p/DATA4), U3.17 (A17), U4.17 (A17)
/A18: U2.A7 (IO/DIFFIO_T11n/PADD18), U3.16 (A18), U4.16 (A18)
/A19: U2.B8 (IO/DIFFIO_T12p/DATA3), U3.9 (A19), U4.9 (A19)
/A20: U2.C10 (IO), U3.45 (I/O15/A20), U4.45 (I/O15/A20)
/CC1: R2.1, U6.4 (CC1), USB1.A5 (CC1)
/CC2: R3.1, U6.5 (CC2), USB1.B5 (CC2)
/CE1: U2.B1 (IO/DIFFIO_L1n), U3.26 (#CE1), U4.26 (#CE1)
/CLK_50M: R9.1, U2.G21 (CLK4/DIFFCLK_2p)
/CONF_DONE: Q3.1 (G), R32.1, U2.M18 (CONF_DONE/CONF_DONE)
/EXTIO0: H6.2, U2.F22 (IO/DIFFIO_R11n)
/EXTIO1: H6.3, U2.F21 (IO/DIFFIO_R11p)
/EXTIO2: H6.4, U2.E22 (IO/DIFFIO_R9n/nWE)
/EXTIO3: H6.5, U2.E21 (IO/DIFFIO_R9p/nOE)
/EXTIO4: H6.6, U2.D22 (IO/DIFFIO_R7n)
/EXTIO5: H6.7, U2.D21 (IO/DIFFIO_R7p)
/FPGA_ASD0: U2.D1 (IO/DIFFIO_L4n/DATA1/ASDO), U17.5 (DI(IO0))
/FPGA_DATA0: U2.K1 (IO/DATA0), U17.2 (DO(IO1))
/FPGA_DCLK: U2.K2 (DCLK/DCLK), U17.6 (CLK)
/FPGA_NCSO: R37.1, U2.E2 (IO/DIFFIO_L6p/FLASH_nCE/nCSO), U17.1 (CS#)
/HI_D0: U2.A17 (IO/DIFFIO_T25n/PADD1), U3.29 (I/O0)
/HI_D1: U2.B17 (IO/DIFFIO_T25p/PADD2), U3.31 (I/O1)
/HI_D2: U2.A18 (IO/DIFFIO_T27n), U3.33 (I/O2)
/HI_D3: U2.B18 (IO/DIFFIO_T27p/PADD0), U3.35 (I/O3)
/HI_D4: U2.A19 (IO/RDN4), U3.38 (I/O4)
/HI_D5: U2.B19 (IO/RUP4), U3.40 (I/O5)
/HI_D6: U2.A20 (IO/PLL2_CLKOUTn), U3.42 (I/O6)
/HI_D7: U2.B20 (IO/PLL2_CLKOUTp), U3.44 (I/O7)
/INIT_L_FPGA: Q1.2 (S), R16.1, U2.W20 (IO/DIFFIO_R34n)
/IO_RX1: H1.7, R48.2, U2.C1 (IO/DIFFIO_L3n), U5.6 (TXD)
/IO_TX1: H1.6, R49.2, U2.D2 (IO/DIFFIO_L4p), U5.7 (RXD)
/LED_A0: LED33.2 (A), U19.1 (LED1)
/LED_A1: LED45.2 (A), U19.2 (LED2)
/LED_A2: LED27.2 (A), U19.3 (LED3)
/LED_A3: LED39.2 (A), U19.4 (LED4)
/LED_A4: LED28.2 (A), U19.5 (LED5)
/LED_A5: LED40.2 (A), U19.6 (LED6)
/LED_A6: LED46.2 (A), U19.7 (LED7)
/LED_A7: LED34.2 (A), U19.8 (LED8)
/LED_A8: LED47.2 (A), U19.9 (LED9)
/LED_A9: LED41.2 (A), U19.10 (LED10)
/LED_A10: LED29.2 (A), U19.11 (LED11)
/LED_A11: LED35.2 (A), U19.12 (LED12)
/LED_A12: LED30.2 (A), U19.13 (LED13)
/LED_A13: LED42.2 (A), U19.14 (LED14)
/LED_A14: LED48.2 (A), U19.15 (LED15)
/LED_A15: LED36.2 (A), U19.16 (LED16)
/LED_A16: LED31.2 (A), U19.17 (LED17)
/LED_A17: LED43.2 (A), U19.18 (LED18)
/LED_A18: LED37.2 (A), U19.19 (LED19)
/LED_A19: LED38.2 (A), U19.20 (LED20)
/LED_A20: LED32.2 (A), U19.21 (LED21)
/LED_A21: LED44.2 (A), U19.22 (LED22)
/LED_ABORT: R42.3, U2.R17 (IO/VREFB5N1)
/LED_ADDR_EN: U2.Y4 (IO/VREFB3N1), U19.30 (EN)
/LED_D0: LED11.2 (A), U18.1 (LED1)
/LED_D1: LED17.2 (A), U18.2 (LED2)
/LED_D2: LED23.2 (A), U18.3 (LED3)
/LED_D3: LED12.2 (A), U18.4 (LED4)
/LED_D4: LED18.2 (A), U18.5 (LED5)
/LED_D5: LED24.2 (A), U18.6 (LED6)
/LED_D6: LED19.2 (A), U18.7 (LED7)
/LED_D7: LED25.2 (A), U18.8 (LED8)
/LED_D8: LED13.2 (A), U18.9 (LED9)
/LED_D9: LED20.2 (A), U18.10 (LED10)
/LED_D10: LED26.2 (A), U18.11 (LED11)
/LED_D11: LED14.2 (A), U18.12 (LED12)
/LED_D12: LED21.2 (A), U18.13 (LED13)
/LED_D13: LED15.2 (A), U18.14 (LED14)
/LED_D14: LED16.2 (A), U18.15 (LED15)
/LED_D15: LED22.2 (A), U18.16 (LED16)
/LED_DATA_EN: U2.Y8 (IO/DIFFIO_B13p), U18.30 (EN)
/LED_FETCH: R42.4, U2.R16 (IO/PLL4_CLKOUTn)
/LED_HALT: R42.2, U2.R18 (IO/DIFFIO_R26n)
/LED_I2C_SCL: R46.2, U2.Y7 (IO/DIFFIO_B10n), U18.29 (SCL), U19.29 (SCL)
/LED_I2C_SDA: R47.2, U2.Y6 (IO), U18.28 (SDA), U19.28 (SDA)
/LED_INACK: R43.3, U2.R13 (IO)
/LED_IOSPACE: R43.4, U2.R12 (IO/DIFFIO_B5n)
/LED_READ: R43.1, U2.R15 (IO/DIFFIO_B32n)
/LED_RUN: R42.1, U2.R19 (IO/DIFFIO_R26p)
/LED_WRITE: R43.2, U2.R14 (IO/DIFFIO_B32p)
/LO_D0: U2.AA1 (IO/DIFFIO_L27n), U4.29 (I/O0)
/LO_D1: U2.Y2 (IO/DIFFIO_L25p), U4.31 (I/O1)
/LO_D2: U2.Y1 (IO/DIFFIO_L25n), U4.33 (I/O2)
/LO_D3: U2.W2 (IO/DIFFIO_L24p), U4.35 (I/O3)
/LO_D4: U2.W1 (IO/DIFFIO_L24n), U4.38 (I/O4)
/LO_D5: U2.V2 (IO/DIFFIO_L21p), U4.40 (I/O5)
/LO_D6: U2.V1 (IO/DIFFIO_L21n), U4.42 (I/O6)
/LO_D7: U2.U2 (IO/DIFFIO_L20p), U4.44 (I/O7)
/OE: U2.B2 (IO/DIFFIO_L1p), U3.28 (#OE), U4.28 (#OE)
/SD_CLK: R38.2, U2.R22 (IO/DIFFIO_R25n)
/SD_CS: R39.1, U2.P22 (IO/DIFFIO_R24n), U16.1 (CD/DAT3)
/SD_MISO: R41.1, U2.R21 (IO/DIFFIO_R25p), U16.7 (DAT0)
/SD_MOSI: R40.1, U2.P21 (IO/DIFFIO_R24p), U16.2 (CMD)
/TCK: H1.3, R28.1, U2.L2 (TCK/TCK)
/TDI: H1.1, R30.1, U2.L5 (TDI/TDI)
/TDO: H1.2, U2.L4 (TDO/TDO)
/TMS: H1.4, R29.1, U2.L1 (TMS/TMS)
/USB_D_N: U5.2 (UD-), USB2.A7 (Dn1), USB2.B7 (Dn2)
/USB_D_P: U5.1 (UD+), USB2.A6 (Dp1), USB2.B6 (Dp2)
/WE_HI: U2.C3 (IO/DIFFIO_T2n), U3.11 (#WE)
/WE_LO: U2.C4 (IO/DIFFIO_T2p/DATA12), U4.11 (#WE)
/nCONFIG: R33.1, S6.1 (A), U2.K5 (nCONFIG/nCONFIG)
/nSTATUS: R31.1, U2.K6 (nSTATUS/nSTATUS)
AIO0: U1.2 (AIO0), U8.2 (A1)
AIO0_L: U2.AA3 (IO/PLL1_CLKOUTp), U8.18 (B1)
AIO1: U1.3 (AIO1), U8.3 (A2)
AIO1_L: U2.AB3 (IO/PLL1_CLKOUTn), U8.17 (B2)
AIO2: U1.4 (AIO2), U8.4 (A3)
AIO2_L: U2.AA4 (IO/DIFFIO_B8p), U8.16 (B3)
AIO3: U1.5 (AIO3), U8.5 (A4)
AIO3_L: U2.AB4 (IO/DIFFIO_B8n), U8.15 (B4)
BS0: U1.17 (BS0), U8.8 (A7)
BS0_L: U2.AA7 (IO/DIFFIO_B12p), U8.12 (B7)
BS1: U1.18 (BS1), U8.9 (A8)
BS1_L: U2.AB7 (IO/DIFFIO_B12n), U8.11 (B8)
CLK2: R15.1, U1.34 (CLK2)
CLK2_L: U2.U22 (IO/DIFFIO_R27n), U13.11 (B8)
CONT: U1.32 (CONT), U13.8 (A7)
CONT_L: U2.U21 (IO/DIFFIO_R27p), U13.12 (B7)
DAL0: U1.57 (DAL0), U9.5 (A4)
DAL0_L: U2.AB9 (IO/DIFFIO_B16n), U9.15 (B4)
DAL1: U1.49 (DAL1), U11.5 (A4)
DAL1_L: U2.AA15 (IO/DIFFIO_B22p), U11.15 (B4)
DAL2: U1.48 (DAL2), U11.6 (A5)
DAL2_L: U2.AB16 (IO/DIFFIO_B24n), U11.14 (B5)
DAL3: U1.47 (DAL3), U11.7 (A6)
DAL3_L: U2.AA16 (IO/DIFFIO_B24p), U11.13 (B6)
DAL4: U1.44 (DAL4), U11.8 (A7)
DAL4_L: U2.AB17 (IO/DIFFIO_B25n), U11.12 (B7)
DAL5: U1.43 (DAL5), U11.9 (A8)
DAL5_L: U2.AA17 (IO/DIFFIO_B25p), U11.11 (B8)
DAL6: U1.60 (DAL6), U9.2 (A1)
DAL6_L: U2.AA8 (IO/DIFFIO_B15p), U9.18 (B1)
DAL7: U1.59 (DAL7), U9.3 (A2)
DAL7_L: U2.AB8 (IO/DIFFIO_B15n), U9.17 (B2)
DAL8: U1.58 (DAL8), U9.4 (A3)
DAL8_L: U2.AA9 (IO/DIFFIO_B16p), U9.16 (B3)
DAL9: U1.56 (DAL9), U9.6 (A5)
DAL9_L: U2.AA10 (IO/DIFFIO_B18n), U9.14 (B5)
DAL10: U1.55 (DAL10), U9.7 (A6)
DAL10_L: U2.AB10 (IO), U9.13 (B6)
DAL11: U1.54 (DAL11), U9.8 (A7)
DAL11_L: U2.AB13 (IO/DIFFIO_B19n), U9.12 (B7)
DAL12: U1.53 (DAL12), U9.9 (A8)
DAL12_L: U2.AA13 (IO/DIFFIO_B19p), U9.11 (B8)
DAL13: U1.52 (DAL13), U11.2 (A1)
DAL13_L: U2.AB14 (IO/DIFFIO_B20n), U11.18 (B1)
DAL14: U1.51 (DAL14), U11.3 (A2)
DAL14_L: U2.AA14 (IO/DIFFIO_B20p), U11.17 (B2)
DAL15: U1.50 (DAL15), U11.4 (A3)
DAL15_L: U2.AB15 (IO/DIFFIO_B22n), U11.16 (B3)
DAL16: U1.26 (DAL16), U12.8 (A7)
DAL16_L: U2.AA21 (IO/DIFFIO_R35p), U12.12 (B7)
DAL17: U1.25 (DAL17), U12.7 (A6)
DAL17_L: U2.AA20 (IO/DIFFIO_B30p), U12.13 (B6)
DAL18: U1.24 (DAL18), U12.6 (A5)
DAL18_L: U2.AB20 (IO/DIFFIO_B30n), U12.14 (B5)
DAL19: U1.23 (DAL19), U12.5 (A4)
DAL19_L: U2.AA19 (IO/RUP2), U12.15 (B4)
DAL20: U1.22 (DAL20), U12.4 (A3)
DAL20_L: U2.AB19 (IO/RDN2), U12.16 (B3)
DAL21: U1.21 (DAL21), U12.3 (A2)
DAL21_L: U2.AA18 (IO), U12.17 (B2)
DV: R19.1, U1.42 (DV), U12.9 (A8)
DV_L: U2.Y17 (IO/DIFFIO_B29n), U12.11 (B8)
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

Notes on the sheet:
POWER TREE
FRONT PANEL LED
FPGA CONFIG
DCJ-11 CPU
FRONT PANEL LED CONTROL
FPGA

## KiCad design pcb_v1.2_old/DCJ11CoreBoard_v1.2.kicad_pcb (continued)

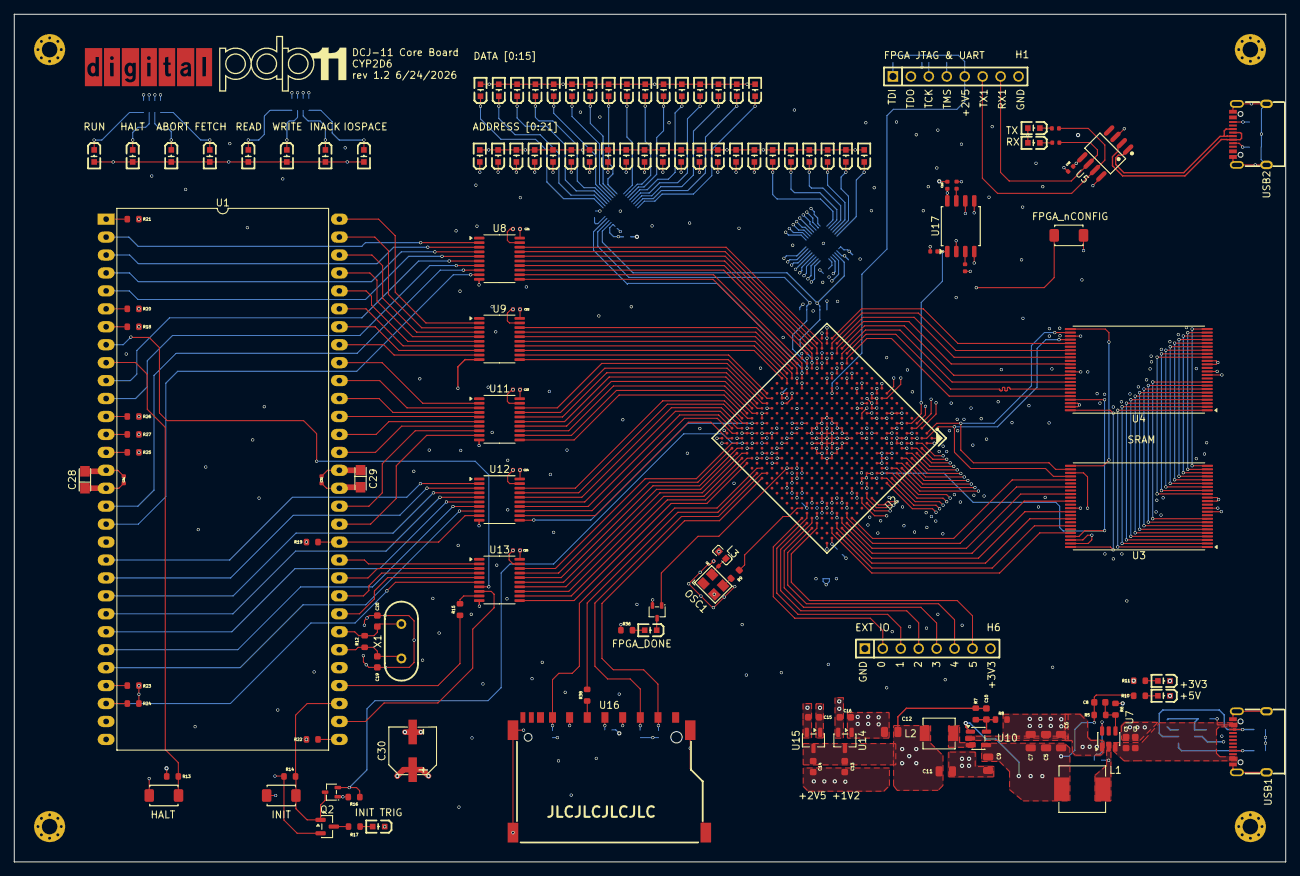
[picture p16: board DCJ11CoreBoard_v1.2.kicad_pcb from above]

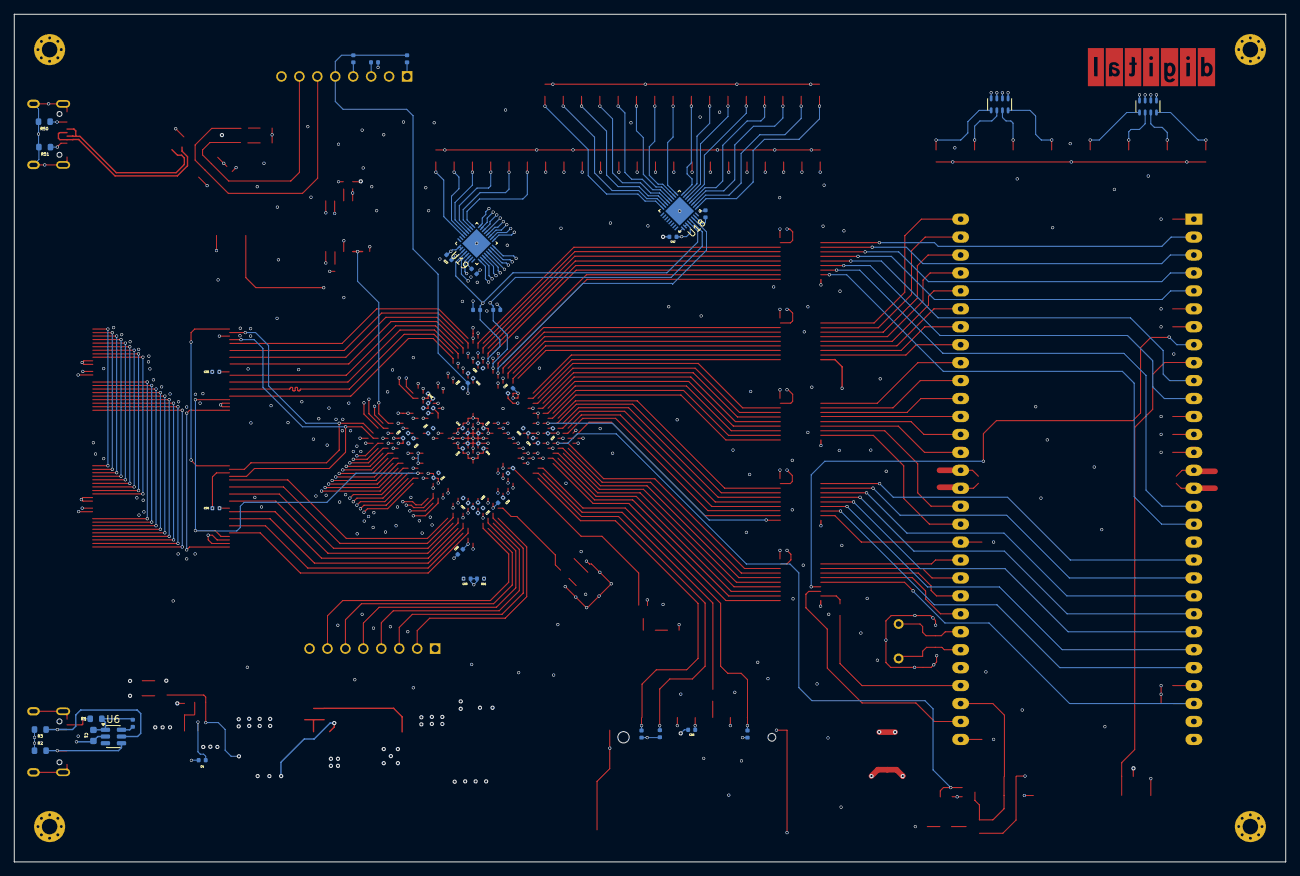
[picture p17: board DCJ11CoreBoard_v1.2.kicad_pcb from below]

Board: 6 copper layers, 180.0 x 120.0 mm, 200 parts (54 on the bottom side), 251 nets.

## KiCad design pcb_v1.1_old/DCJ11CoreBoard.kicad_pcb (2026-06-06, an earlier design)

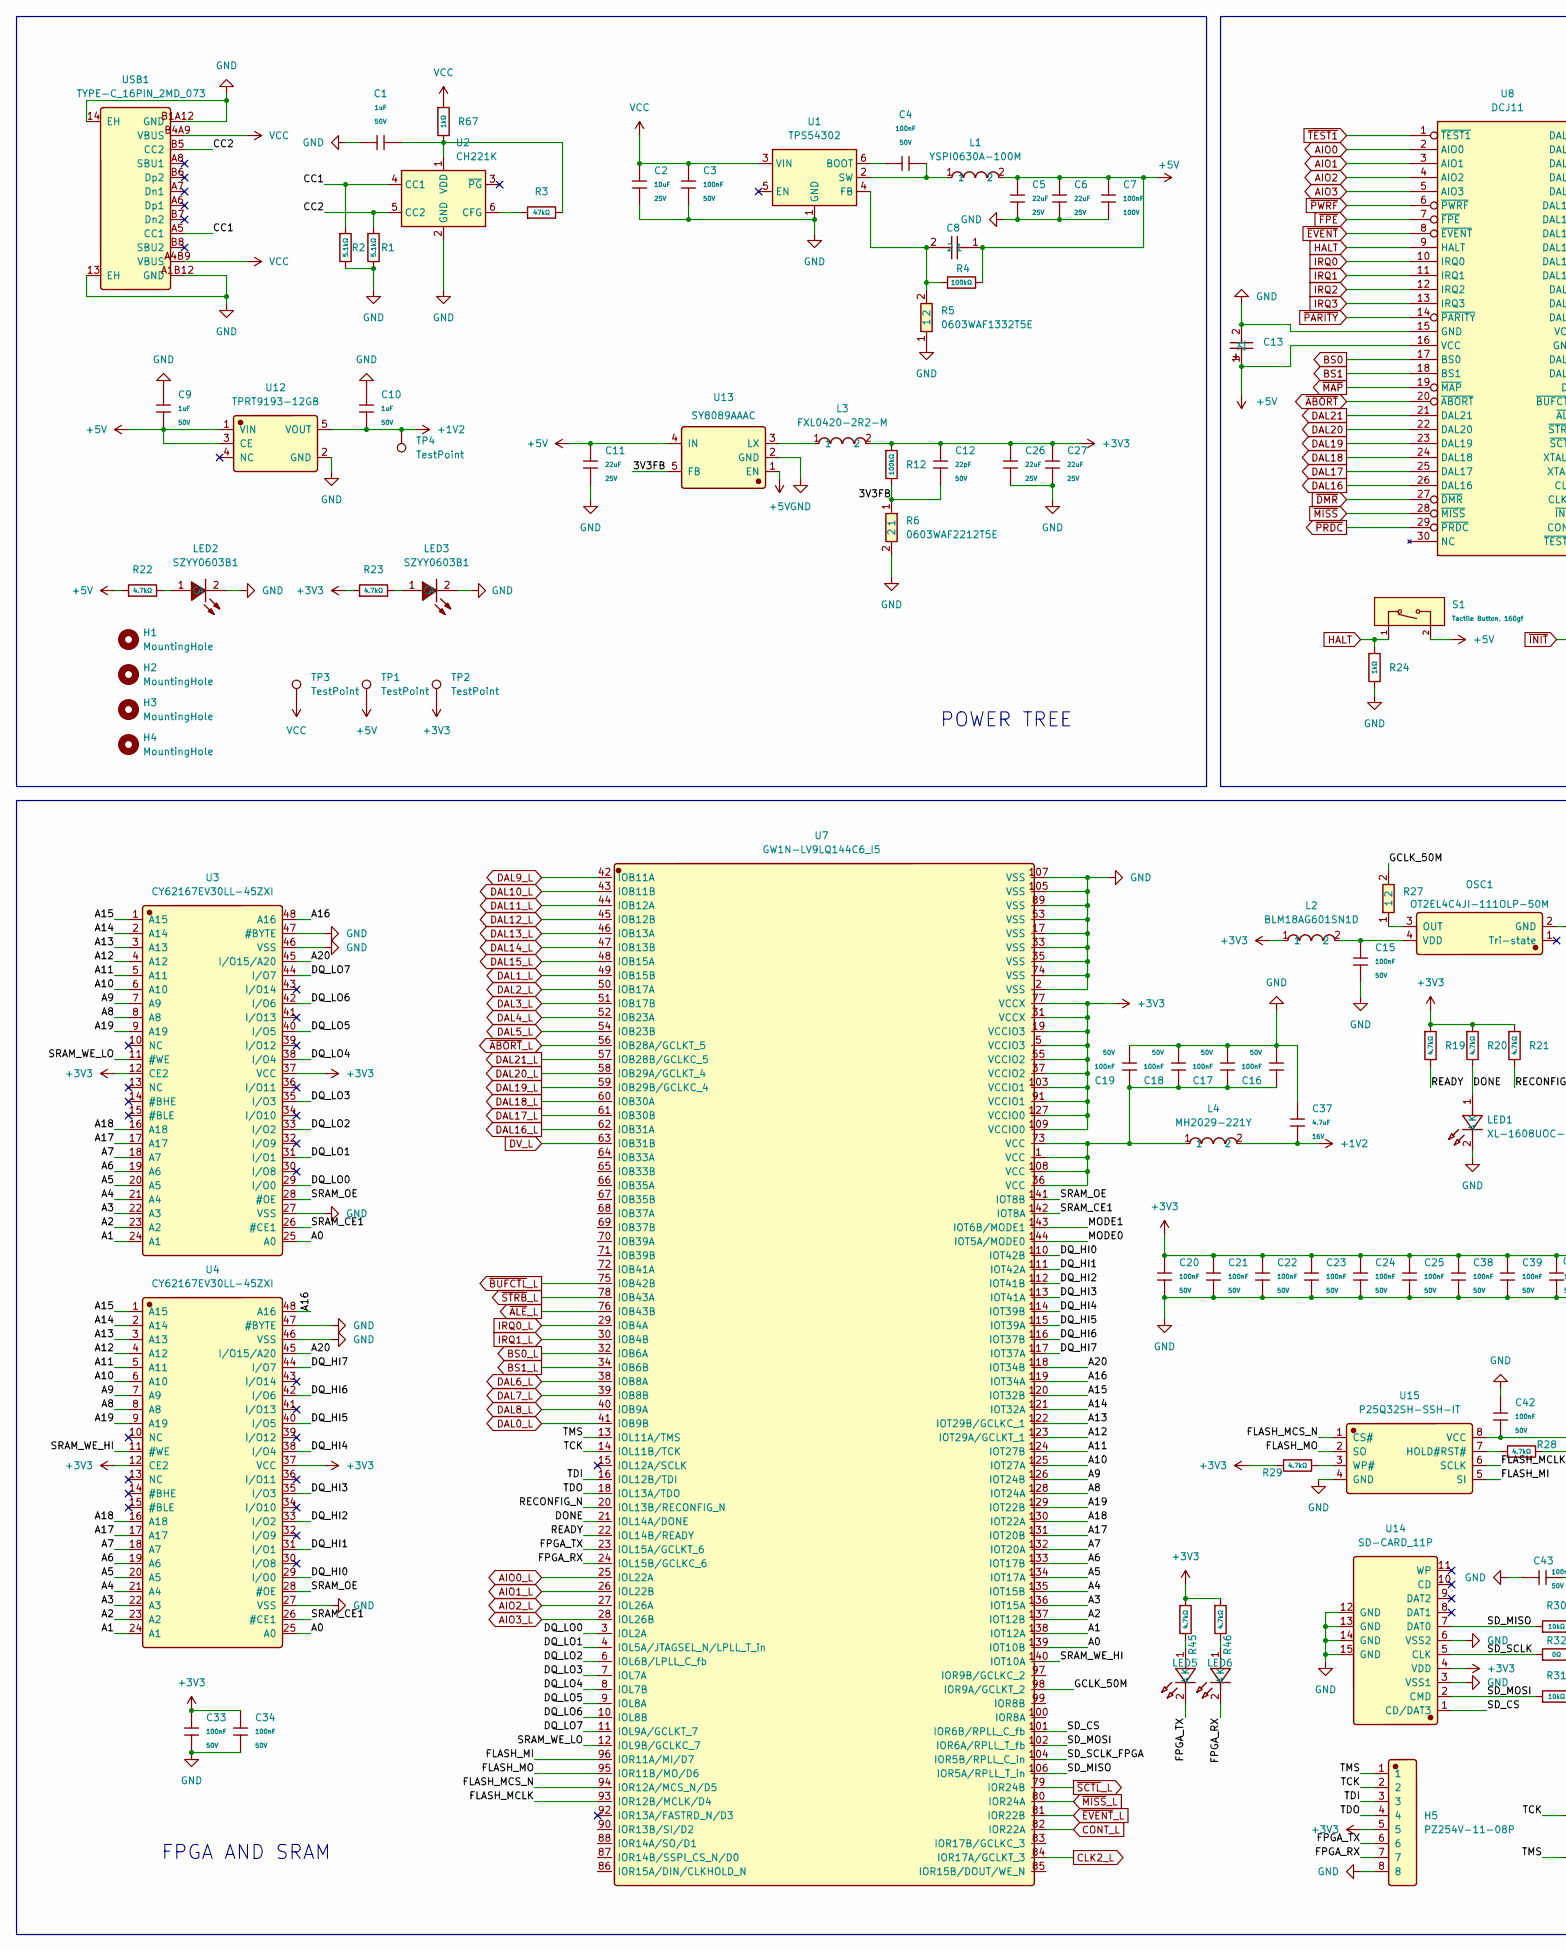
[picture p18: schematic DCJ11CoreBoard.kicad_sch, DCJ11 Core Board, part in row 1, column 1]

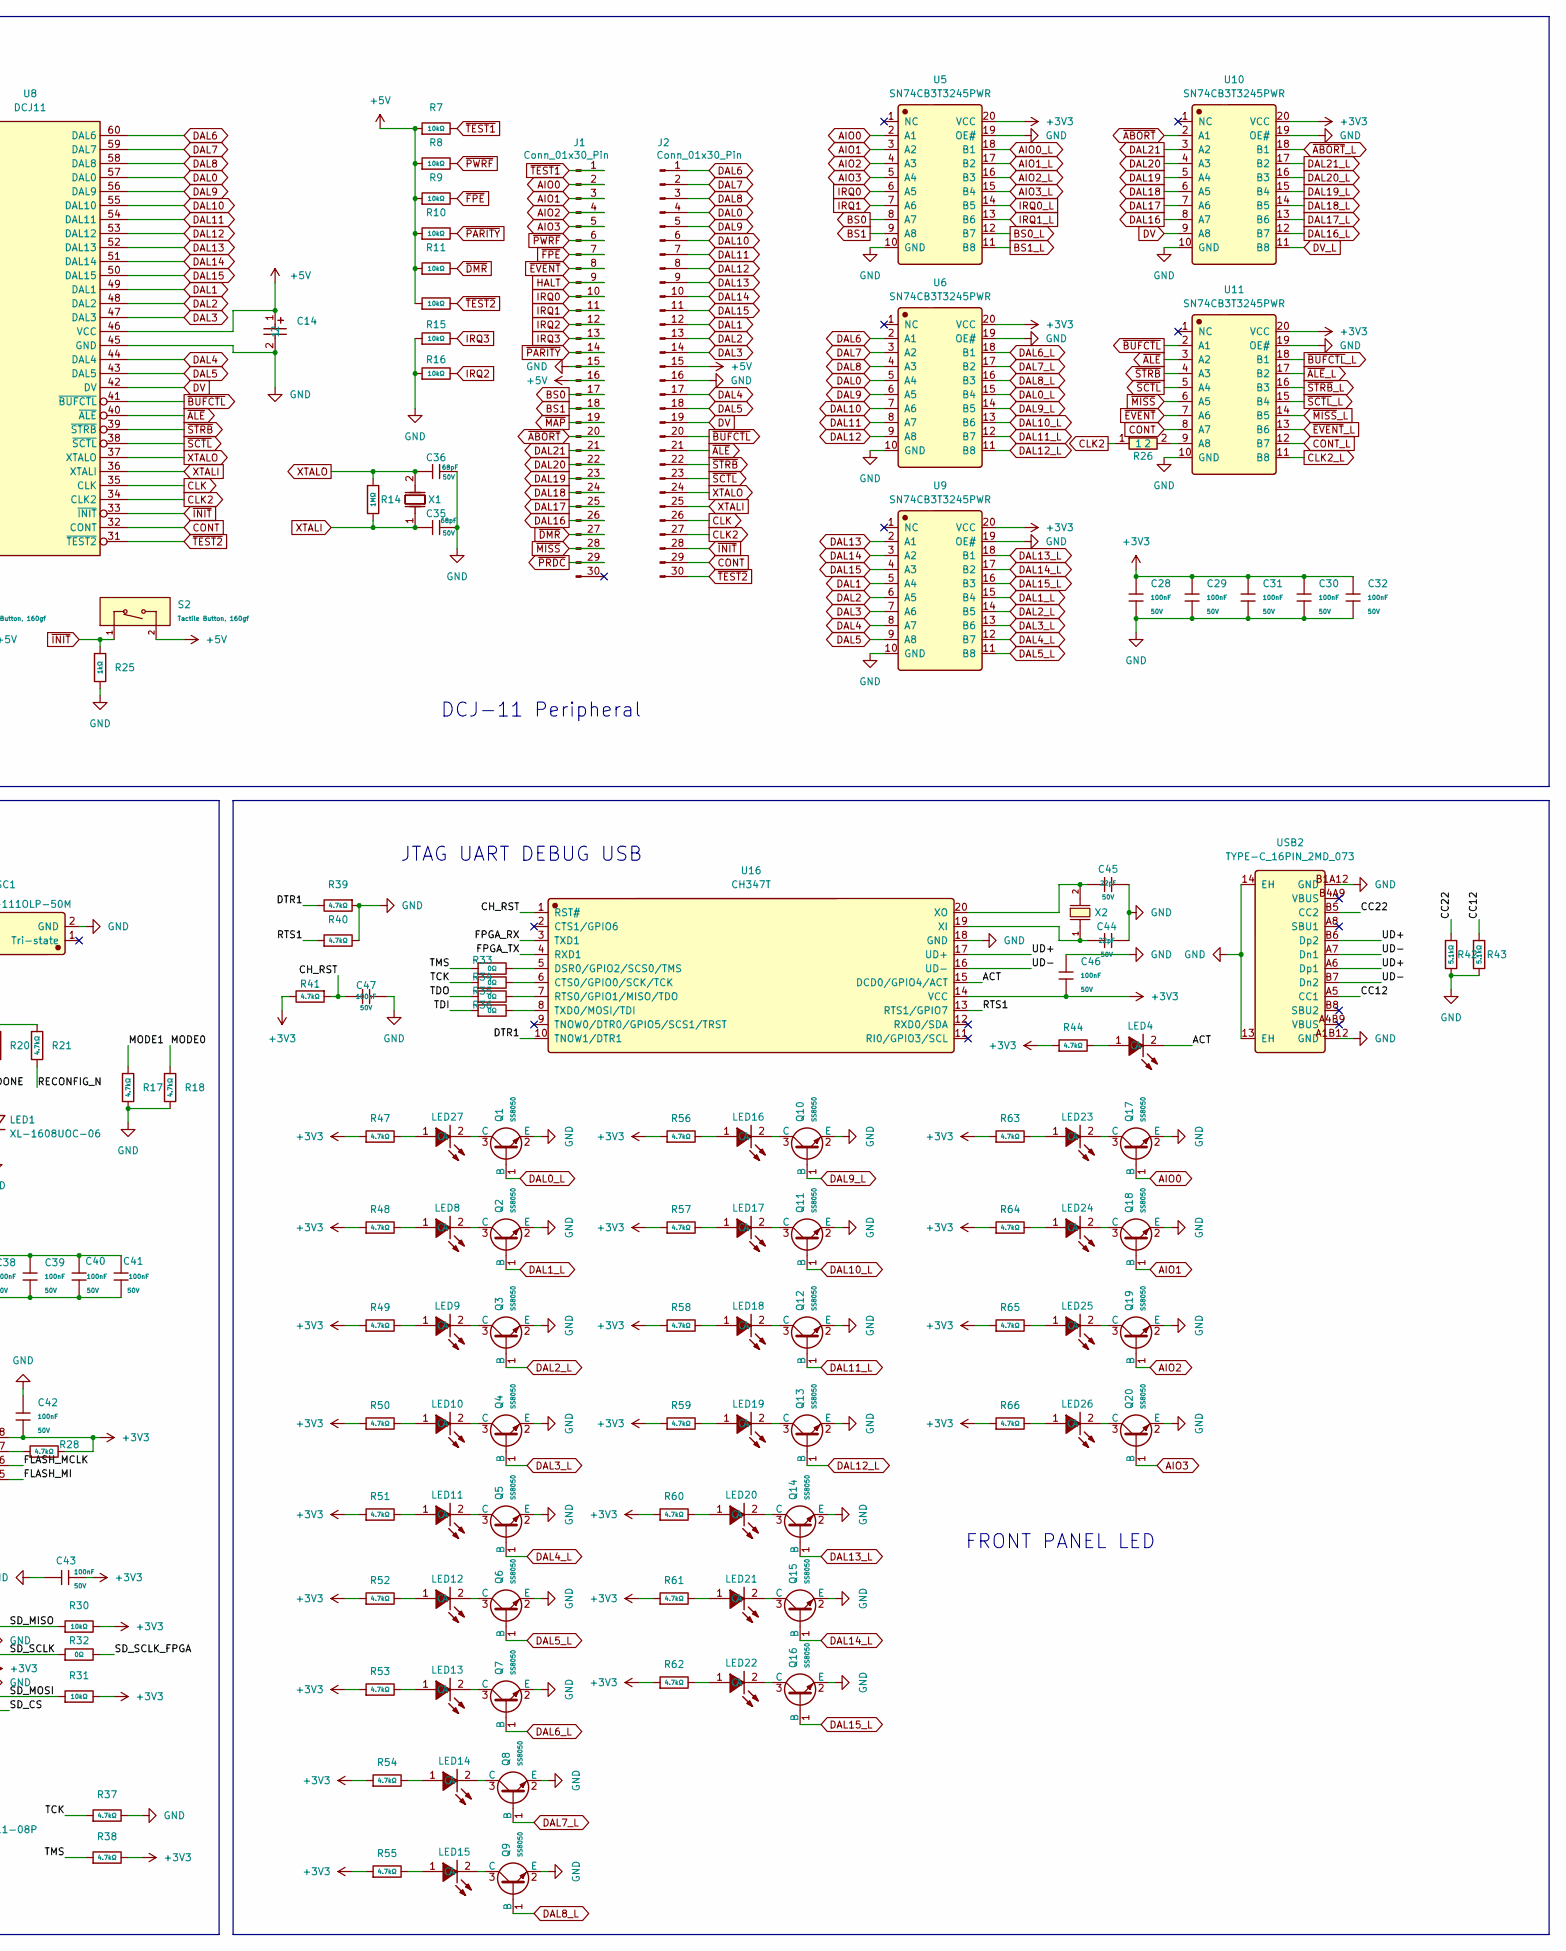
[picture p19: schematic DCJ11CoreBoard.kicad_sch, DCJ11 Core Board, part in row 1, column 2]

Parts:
C1, C9, C10: 1uF; C_0603; Voltage Rated 50V; Tolerance ±10%; Part CL10A105KB8NNNC; LCSC C15849
C2: 10uF; C_0603; Voltage Rated 25V; Tolerance ±20%; Part CL10A106MA8NRNC; LCSC C96446
C3, C4, C15, C16, C17, C18, C19, C20, C21, C22, C23, C24, C25, C28, C29, C30, C31, C32, C33, C34, C38, C39, C40, C41, C42, C43, C46, C47: 100nF; C_0603; Voltage Rated 50V; Tolerance ±10%; Part CC0603KRX7R9BB104; LCSC C14663
C5, C6, C11, C26, C27: 22uF; C_0805; Voltage Rated 25V; Tolerance ±20%; Part CL21A226MAQNNNE; LCSC C45783
C7: 100nF; C_0805; Voltage Rated 100V; Tolerance ±10%; Part CL21B104KCFNNNE; LCSC C28233
C8: CC0603JRNPO9BN750; C_0603; Manufacturer Part CC0603JRNPO9BN750; LCSC C282074
C12, C44, C45: 22pF; C_0603; Voltage Rated 50V; Tolerance ±5%; Part CL10C220JB8NNNC; LCSC C1653
C13, C14: TAJA334K035RNJ; Manufacturer Part TAJA334K035RNJ; LCSC C8014
C35, C36: 68pF; C_0603; Voltage Rated 50V; Tolerance ±5%; Part CL10C680JB8NNNC; LCSC C28262
C37: 4.7uF; C_0603; Voltage Rated 16V; Tolerance ±10%; Part CL10A475KO8NNNC; LCSC C19666
H1, H2, H3, H4: MountingHole; MountingHole_2.5mm
H5: PZ254V-11-08P; Manufacturer Part PZ254V-11-08P; LCSC C492407
J1, J2: Conn_01x30_Pin; PinHeader_1x30_P2.54mm_Vertical
L1: YSPI0630A-100M; Manufacturer Part YSPI0630A-100M; LCSC C497871
L2: BLM18AG601SN1D; Manufacturer Part BLM18AG601SN1D; LCSC C19330
L3: FXL0420-2R2-M; Manufacturer Part FXL0420-2R2-M; LCSC C167206
L4: MH2029-221Y; Manufacturer Part MH2029-221Y; LCSC C840594
LED1, LED5, LED6: XL-1608UOC-06; Manufacturer Part XL-1608UOC-06; LCSC C965800
LED2, LED3, LED4, LED8, LED9, LED10, LED11, LED12, LED13, LED14, LED15, LED16, LED17, LED18, LED19, LED20, LED21, LED22, LED23, LED24, LED25, LED26, LED27: SZYY0603B1; Manufacturer Part SZYY0603B1; LCSC C19712531
OSC1: OT2EL4C4JI-111OLP-50M; Manufacturer Part OT2EL4C4JI-111OLP-50M; LCSC C5203552
Q1, Q2, Q3, Q4, Q5, Q6, Q7, Q8, Q9, Q10, Q11, Q12, Q13, Q14, Q15, Q16, Q17, Q18, Q19, Q20: SS8050; Q_SOT-23; Part SS8050; LCSC C431710
R1, R2, R42, R43: 5.1kΩ; R_0603; Overload Voltage (Max) 75V; Tolerance ±1%; Part 0603WAF5101T5E; LCSC C23186
R3: 47kΩ; R_0603; Overload Voltage (Max) 75V; Tolerance ±1%; Part 0603WAF4702T5E; LCSC C25819
R4, R12: 100kΩ; R_0603; Overload Voltage (Max) 75V; Tolerance ±1%; Part 0603WAF1003T5E; LCSC C25803
R5: 0603WAF1332T5E; R_0603; Manufacturer Part 0603WAF1332T5E; LCSC C25952
R6: 0603WAF2212T5E; R_0603; Manufacturer Part 0603WAF2212T5E; LCSC C25961
R7, R8, R9, R10, R11, R13, R15, R16, R30, R31: 10kΩ; R_0603; Overload Voltage (Max) 75V; Tolerance ±1%; Part 0603WAF1002T5E; LCSC C25804
R14: 1MΩ; R_0603; Overload Voltage (Max) 75V; Tolerance ±1%; Part 0603WAF1004T5E; LCSC C22935
R17, R18, R19, R20, R21, R22, R23, R28, R29, R37, R38, R39, R40, R41, R44, R45, R46, R47, R48, R49, R50, R51, R52, R53, R54, R55, R56, R57, R58, R59, R60, R61, R62, R63, R64, R65, R66: 4.7kΩ; R_0603; Overload Voltage (Max) 75V; Tolerance ±1%; Part 0603WAF4701T5E; LCSC C23162
R24, R25, R67: 1kΩ; R_0603; Overload Voltage (Max) 75V; Tolerance ±1%; Part 0603WAF1001T5E; LCSC C21190
R26, R27: 0603WAF220JT5E; R_0603; Manufacturer Part 0603WAF220JT5E; LCSC C23345
R32, R33, R34, R35, R36: 0Ω; R_0603; Overload Voltage (Max) 75V; Tolerance ±1%; Part 0603WAF0000T5E; LCSC C21189
S1, S2: Tactile Button, 160gf; SW_TS-1088-AR02016; Voltage Rating (Dc) 12V; Part TS-1088-AR02016; LCSC C720477
TP1, TP2, TP3, TP4: TestPoint; TestPoint_Pad_D1.0mm
U1: TPS54302; SOT-23-6
U2: CH221K; SOT-23-6
U3, U4: CY62167EV30LL-45ZXI; TSOP-I-48_18.4x12mm_P0.5mm; Manufacturer Part CY62167EV30LL-45ZXI; LCSC C115715
U5, U6, U9, U10, U11: SN74CB3T3245PWR; TSSOP-20_4.4x6.5mm_P0.65mm; Manufacturer Part SN74CB3T3245PWR; LCSC C15298
U7: GW1N-LV9LQ144C6_I5; Manufacturer Part GW1N-LV9LQ144C6/I5; LCSC C5799572
U8: DCJ11; DIP-60_W33.02mm_LongPads
U12: TPRT9193-12GB; Manufacturer Part TPRT9193-12GB; LCSC C7202982
U13: SY8089AAAC; SOT-23-5; Manufacturer Part SY8089AAAC; LCSC C78988
U14: SD-CARD_11P; Manufacturer Part SD-CARD 11P; LCSC C7529393
U15: P25Q32SH-SSH-IT; Manufacturer Part P25Q32SH-SSH-IT; LCSC C2833294
U16: CH347T; Manufacturer Part CH347T; LCSC C5122332
USB1, USB2: TYPE-C_16PIN_2MD_073; Manufacturer Part TYPE-C 16PIN 2MD(073); LCSC C2765186
X1: 9BC18000151060C3; Manufacturer Part 9BC18000151060C3; LCSC C2715887
X2: X50328MSB2GI; CRYSTAL-SMD_L5.0-W3.2; Frequency Tolerance ±10ppm; Part X50328MSB2GI; LCSC C115962

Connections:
+1V2: C10.2, C37.2, L4.2, TP4.1 (1_1), U12.5 (VOUT)
+3V3: C12.1, C20.1, C21.1, C22.1, C23.1, C24.1, C25.1, C26.1, C27.1, C28.1, C29.1, C30.1, C31.1, C32.1, C33.1, C34.1, C38.1, C39.1, C40.1, C41.1, C42.2, C43.1, C46.2, H5.5, L2.1, L3.2, R12.1, R19.1, R20.1, R21.1, R23.1, R28.2, R29.2, R30.2, R31.2, R38.2, R41.2, R44.1, R45.1, R46.1, R47.1, R48.1, R49.1, R50.1, R51.1, R52.1, R53.1, R54.1, R55.1, R56.1, R57.1, R58.1, R59.1, R60.1, R61.1, R62.1, R63.1, R64.1, R65.1, R66.1, TP2.1 (1_1), U3.12 (CE2), U3.37 (VCC), U4.12 (CE2), U4.37 (VCC), U5.20 (VCC), U6.20 (VCC), U7.5 (VCCIO3), U7.19 (VCCIO3), U7.31 (VCCX), U7.37 (VCCIO2), U7.55 (VCCIO2), U7.77 (VCCX), U7.91 (VCCIO1), U7.103 (VCCIO1), U7.109 (VCCIO0), U7.127 (VCCIO0), U9.20 (VCC), U10.20 (VCC), U11.20 (VCC), U14.4 (VDD), U15.8 (VCC), U16.14 (VCC)
+5V: C5.1, C6.1, C7.1, C8.1, C9.1, C11.1, C13.1, C14.1, J1.16, J2.15, L1.2, R4.2, R7.1, R8.1, R9.1, R10.1, R11.1, R13.1, R22.1, S1.2 (B), S2.2 (B), TP1.1 (1_1), U8.16 (VCC), U8.46 (VCC), U12.1 (VIN), U12.3 (CE), U13.1 (EN), U13.4 (IN)
/3V3FB: C12.2, R6.1, R12.2, U13.5 (FB)
/A0: U3.25 (A0), U4.25 (A0), U7.139 (IOT10B)
/A1: U3.24 (A1), U4.24 (A1), U7.138 (IOT12A)
/A2: U3.23 (A2), U4.23 (A2), U7.137 (IOT12B)
/A3: U3.22 (A3), U4.22 (A3), U7.136 (IOT15A)
/A4: U3.21 (A4), U4.21 (A4), U7.135 (IOT15B)
/A5: U3.20 (A5), U4.20 (A5), U7.134 (IOT17A)
/A6: U3.19 (A6), U4.19 (A6), U7.133 (IOT17B)
/A7: U3.18 (A7), U4.18 (A7), U7.132 (IOT20A)
/A8: U3.8 (A8), U4.8 (A8), U7.128 (IOT24A)
/A9: U3.7 (A9), U4.7 (A9), U7.126 (IOT24B)
/A10: U3.6 (A10), U4.6 (A10), U7.125 (IOT27A)
/A11: U3.5 (A11), U4.5 (A11), U7.124 (IOT27B)
/A12: U3.4 (A12), U4.4 (A12), U7.123 (IOT29A/GCLKT_1)
/A13: U3.3 (A13), U4.3 (A13), U7.122 (IOT29B/GCLKC_1)
/A14: U3.2 (A14), U4.2 (A14), U7.121 (IOT32A)
/A15: U3.1 (A15), U4.1 (A15), U7.120 (IOT32B)
/A16: U3.48 (A16), U4.48 (A16), U7.119 (IOT34A)
/A17: U3.17 (A17), U4.17 (A17), U7.131 (IOT20B)
/A18: U3.16 (A18), U4.16 (A18), U7.130 (IOT22A)
/A19: U3.9 (A19), U4.9 (A19), U7.129 (IOT22B)
/A20: U3.45 (I/O15/A20), U4.45 (I/O15/A20), U7.118 (IOT34B)
/ACT: LED4.2 (C), U16.15 (DCD0/GPIO4/ACT)
/CC1: R2.1, U2.4 (CC1), USB1.A5 (CC1)
/CC2: R1.1, U2.5 (CC2), USB1.B5 (CC2)
/CC12: R43.1, USB2.A5 (CC1)
/CC22: R42.1, USB2.B5 (CC2)
/CH_RST: C47.1, R41.1, U16.1 (RST#)
/DONE: LED1.1 (K), R20.2, U7.21 (IOL14A/DONE)
/DQ_HI0: U4.29 (I/O0), U7.110 (IOT42B)
/DQ_HI1: U4.31 (I/O1), U7.111 (IOT42A)
/DQ_HI2: U4.33 (I/O2), U7.112 (IOT41B)
/DQ_HI3: U4.35 (I/O3), U7.113 (IOT41A)
/DQ_HI4: U4.38 (I/O4), U7.114 (IOT39B)
/DQ_HI5: U4.40 (I/O5), U7.115 (IOT39A)
/DQ_HI6: U4.42 (I/O6), U7.116 (IOT37B)
/DQ_HI7: U4.44 (I/O7), U7.117 (IOT37A)
/DQ_LO0: U3.29 (I/O0), U7.3 (IOL2A)
/DQ_LO1: U3.31 (I/O1), U7.4 (IOL5A/JTAGSEL_N/LPLL_T_in)
/DQ_LO2: U3.33 (I/O2), U7.6 (IOL6B/LPLL_C_fb)
/DQ_LO3: U3.35 (I/O3), U7.7 (IOL7A)
/DQ_LO4: U3.38 (I/O4), U7.8 (IOL7B)
/DQ_LO5: U3.40 (I/O5), U7.9 (IOL8A)
/DQ_LO6: U3.42 (I/O6), U7.10 (IOL8B)
/DQ_LO7: U3.44 (I/O7), U7.11 (IOL9A/GCLKT_7)
/DTR1: R39.2, U16.10 (TNOW1/DTR1)
/FLASH_MCLK: U7.93 (IOR12B/MCLK/D4), U15.6 (SCLK)
/FLASH_MCS_N: U7.94 (IOR12A/MCS_N/D5), U15.1 (CS#)
/FLASH_MI: U7.96 (IOR11A/MI/D7), U15.5 (SI)
/FLASH_MO: U7.95 (IOR11B/MO/D6), U15.2 (SO)
/FPGA_RX: H5.7, LED6.2 (A), U7.24 (IOL15B/GCLKC_6), U16.3 (TXD1)
/FPGA_TX: H5.6, LED5.2 (A), U7.23 (IOL15A/GCLKT_6), U16.4 (RXD1)
/GCLK_50M: R27.2, U7.98 (IOR9A/GCLKT_2)
/MODE0: R18.1, U7.144 (IOT5A/MODE0)
/MODE1: R17.1, U7.143 (IOT6B/MODE1)
/READY: R19.2, U7.22 (IOL14B/READY)
/RECONFIG_N: R21.2, U7.20 (IOL13B/RECONFIG_N)
/RTS1: R40.1, U16.13 (RTS1/GPIO7)
/SD_CS: U7.101 (IOR6B/RPLL_C_fb), U14.1 (CD/DAT3)
/SD_MISO: R30.1, U7.106 (IOR5A/RPLL_T_in), U14.7 (DAT0)
/SD_MOSI: R31.1, U7.102 (IOR6A/RPLL_T_fb), U14.2 (CMD)
/SD_SCLK: R32.1, U14.5 (CLK)
/SD_SCLK_FPGA: R32.2, U7.104 (IOR5B/RPLL_C_in)
/SRAM_CE1: U3.26 (#CE1), U4.26 (#CE1), U7.142 (IOT8A)
/SRAM_OE: U3.28 (#OE), U4.28 (#OE), U7.141 (IOT8B)
/SRAM_WE_HI: U4.11 (#WE), U7.140 (IOT10A)
/SRAM_WE_LO: U3.11 (#WE), U7.12 (IOL9B/GCLKC_7)
/TCK: H5.2, R34.1, R37.1, U7.14 (IOL11B/TCK)
/TDI: H5.3, R36.1, U7.16 (IOL12B/TDI)
/TDO: H5.4, R35.1, U7.18 (IOL13A/TDO)
/TMS: H5.1, R33.1, R38.1, U7.13 (IOL11A/TMS)
/UD+: U16.17 (UD+), USB2.A6 (Dp1), USB2.B6 (Dp2)
/UD-: U16.16 (UD-), USB2.A7 (Dn1), USB2.B7 (Dn2)
AIO0: J1.2, Q17.1 (B), U5.2 (A1), U8.2 (AIO0)
AIO0_L: U5.18 (B1), U7.25 (IOL22A)
AIO1: J1.3, Q18.1 (B), U5.3 (A2), U8.3 (AIO1)
AIO1_L: U5.17 (B2), U7.26 (IOL22B)
AIO2: J1.4, Q19.1 (B), U5.4 (A3), U8.4 (AIO2)
AIO2_L: U5.16 (B3), U7.27 (IOL26A)
AIO3: J1.5, Q20.1 (B), U5.5 (A4), U8.5 (AIO3)
AIO3_L: U5.15 (B4), U7.28 (IOL26B)
BS0: J1.17, U5.8 (A7), U8.17 (BS0)
BS0_L: U5.12 (B7), U7.32 (IOB6A)
BS1: J1.18, U5.9 (A8), U8.18 (BS1)
BS1_L: U5.11 (B8), U7.34 (IOB6B)
CLK: J2.26, U8.35 (CLK)
CLK2: J2.27, R26.1, U8.34 (CLK2)
CLK2_L: U7.84 (IOR17A/GCLKT_3), U11.11 (B8)
CONT: J2.29, U8.32 (CONT), U11.8 (A7)
CONT_L: U7.82 (IOR22A), U11.12 (B7)
DAL0: J2.4, U6.5 (A4), U8.57 (DAL0)
DAL0_L: Q1.1 (B), U6.15 (B4), U7.41 (IOB9B)
DAL1: J2.12, U8.49 (DAL1), U9.5 (A4)
DAL1_L: Q2.1 (B), U7.49 (IOB15B), U9.15 (B4)
DAL2: J2.13, U8.48 (DAL2), U9.6 (A5)
DAL2_L: Q3.1 (B), U7.50 (IOB17A), U9.14 (B5)
DAL3: J2.14, U8.47 (DAL3), U9.7 (A6)
DAL3_L: Q4.1 (B), U7.51 (IOB17B), U9.13 (B6)
DAL4: J2.17, U8.44 (DAL4), U9.8 (A7)
DAL4_L: Q5.1 (B), U7.52 (IOB23A), U9.12 (B7)
DAL5: J2.18, U8.43 (DAL5), U9.9 (A8)
DAL5_L: Q6.1 (B), U7.54 (IOB23B), U9.11 (B8)
DAL6: J2.1, U6.2 (A1), U8.60 (DAL6)
DAL6_L: Q7.1 (B), U6.18 (B1), U7.38 (IOB8A)
DAL7: J2.2, U6.3 (A2), U8.59 (DAL7)
DAL7_L: Q8.1 (B), U6.17 (B2), U7.39 (IOB8B)
DAL8: J2.3, U6.4 (A3), U8.58 (DAL8)
DAL8_L: Q9.1 (B), U6.16 (B3), U7.40 (IOB9A)
DAL9: J2.5, U6.6 (A5), U8.56 (DAL9)
DAL9_L: Q10.1 (B), U6.14 (B5), U7.42 (IOB11A)
DAL10: J2.6, U6.7 (A6), U8.55 (DAL10)
DAL10_L: Q11.1 (B), U6.13 (B6), U7.43 (IOB11B)
DAL11: J2.7, U6.8 (A7), U8.54 (DAL11)
DAL11_L: Q12.1 (B), U6.12 (B7), U7.44 (IOB12A)
DAL12: J2.8, U6.9 (A8), U8.53 (DAL12)
DAL12_L: Q13.1 (B), U6.11 (B8), U7.45 (IOB12B)
DAL13: J2.9, U8.52 (DAL13), U9.2 (A1)
DAL13_L: Q14.1 (B), U7.46 (IOB13A), U9.18 (B1)
DAL14: J2.10, U8.51 (DAL14), U9.3 (A2)
DAL14_L: Q15.1 (B), U7.47 (IOB13B), U9.17 (B2)
DAL15: J2.11, U8.50 (DAL15), U9.4 (A3)
DAL15_L: Q16.1 (B), U7.48 (IOB15A), U9.16 (B3)
DAL16: J1.26, U8.26 (DAL16), U10.8 (A7)
DAL16_L: U7.62 (IOB31A), U10.12 (B7)
DAL17: J1.25, U8.25 (DAL17), U10.7 (A6)
DAL17_L: U7.61 (IOB30B), U10.13 (B6)
DAL18: J1.24, U8.24 (DAL18), U10.6 (A5)
DAL18_L: U7.60 (IOB30A), U10.14 (B5)
DAL19: J1.23, U8.23 (DAL19), U10.5 (A4)
DAL19_L: U7.59 (IOB29B/GCLKC_4), U10.15 (B4)
DAL20: J1.22, U8.22 (DAL20), U10.4 (A3)
DAL20_L: U7.58 (IOB29A/GCLKT_4), U10.16 (B3)
DAL21: J1.21, U8.21 (DAL21), U10.3 (A2)
DAL21_L: U7.57 (IOB28B/GCLKC_5), U10.17 (B2)
DV: J2.19, U8.42 (DV), U10.9 (A8)
DV_L: U7.63 (IOB31B), U10.11 (B8)
GND: C1.1, C2.2, C3.2, C5.2, C6.2, C7.2, C9.2, C10.1, C11.2, C13.2, C14.2, C15.2, C16.2, C17.2, C18.2, C19.2, C20.2, C21.2, C22.2, C23.2, C24.2, C25.2, C26.2, C27.2, C28.2, C29.2, C30.2, C31.2, C32.2, C33.2, C34.2, C35.1, C36.2, C37.1, C38.2, C39.2, C40.2, C41.2, C42.1, C43.2, C44.2, C45.2, C46.1, C47.2, H5.8, J1.15, J2.16, LED1.2 (A), LED2.2 (C), LED3.2 (C), OSC1.2 (GND), Q1.2 (E), Q2.2 (E), Q3.2 (E), Q4.2 (E), Q5.2 (E), Q6.2 (E), Q7.2 (E), Q8.2 (E), Q9.2 (E), Q10.2 (E), Q11.2 (E), Q12.2 (E), Q13.2 (E), Q14.2 (E), Q15.2 (E), Q16.2 (E), Q17.2 (E), Q18.2 (E), Q19.2 (E), Q20.2 (E), R1.2, R2.2, R5.1, R6.2, R15.1, R16.1, R17.2, R18.2, R24.2, R25.2, R37.2, R39.1, R40.2, R42.2, R43.2, U1.1 (GND), U2.2 (GND), U3.27 (VSS), U3.46 (VSS), U3.47 (#BYTE), U4.27 (VSS), U4.46 (VSS), U4.47 (#BYTE), U5.10 (GND), U5.19 (OE#), U6.10 (GND), U6.19 (OE#), U7.2 (VSS), U7.17 (VSS), U7.33 (VSS), U7.35 (VSS), U7.53 (VSS), U7.74 (VSS), U7.89 (VSS), U7.105 (VSS), U7.107 (VSS), U8.15 (GND), U8.45 (GND), U9.10 (GND), U9.19 (OE#), U10.10 (GND), U10.19 (OE#), U11.10 (GND), U11.19 (OE#), U12.2 (GND), U13.2 (GND), U14.3 (VSS1), U14.6 (VSS2), U14.12 (GND), U14.13 (GND), U14.14 (GND), U14.15 (GND), U15.4 (GND), U16.18 (GND), USB1.13 (EH), USB1.14 (EH), USB1.A1B12 (GND), USB1.B1A12 (GND), USB2.13 (EH), USB2.14 (EH), USB2.A1B12 (GND), USB2.B1A12 (GND)
HALT: J1.9, R24.1, S1.1 (A), U8.9 (HALT)
IRQ0: J1.10, U5.6 (A5), U8.10 (IRQ0)
IRQ0_L: U5.14 (B5), U7.29 (IOB4A)
IRQ1: J1.11, U5.7 (A6), U8.11 (IRQ1)
IRQ1_L: U5.13 (B6), U7.30 (IOB4B)
IRQ2: J1.12, R16.2, U8.12 (IRQ2)
IRQ3: J1.13, R15.2, U8.13 (IRQ3)
unnamed: C16.1, C17.1, C18.1, C19.1, L4.1, U7.1 (VCC), U7.36 (VCC), U7.73 (VCC), U7.108 (VCC)
unnamed: LED2.1 (A), R22.2
unnamed: LED3.1 (A), R23.2
unnamed: LED4.1 (A), R44.2
unnamed: LED5.1 (K), R45.2
unnamed: LED6.1 (K), R46.2
unnamed: LED8.1 (A), R48.2
unnamed: LED8.2 (C), Q2.3 (C)
unnamed: LED9.1 (A), R49.2
unnamed: LED9.2 (C), Q3.3 (C)
unnamed: LED10.1 (A), R50.2
unnamed: LED10.2 (C), Q4.3 (C)
unnamed: LED11.1 (A), R51.2
unnamed: LED11.2 (C), Q5.3 (C)
unnamed: LED12.1 (A), R52.2
unnamed: LED12.2 (C), Q6.3 (C)
unnamed: LED13.1 (A), R53.2
unnamed: LED13.2 (C), Q7.3 (C)
unnamed: LED14.1 (A), R54.2
unnamed: LED14.2 (C), Q8.3 (C)
unnamed: LED15.1 (A), R55.2
unnamed: LED15.2 (C), Q9.3 (C)
unnamed: LED16.1 (A), R56.2
unnamed: LED16.2 (C), Q10.3 (C)
unnamed: LED17.1 (A), R57.2
unnamed: LED17.2 (C), Q11.3 (C)
unnamed: LED18.1 (A), R58.2
unnamed: LED18.2 (C), Q12.3 (C)
unnamed: LED19.1 (A), R59.2
unnamed: LED19.2 (C), Q13.3 (C)
unnamed: LED20.1 (A), R60.2
unnamed: LED20.2 (C), Q14.3 (C)
unnamed: LED21.1 (A), R61.2
unnamed: LED21.2 (C), Q15.3 (C)
unnamed: LED22.1 (A), R62.2
unnamed: LED22.2 (C), Q16.3 (C)
unnamed: LED23.1 (A), R63.2
unnamed: LED23.2 (C), Q17.3 (C)
unnamed: LED24.1 (A), R64.2
unnamed: LED24.2 (C), Q18.3 (C)
unnamed: LED25.1 (A), R65.2
unnamed: LED25.2 (C), Q19.3 (C)
unnamed: LED26.1 (A), R66.2
unnamed: LED26.2 (C), Q20.3 (C)
unnamed: LED27.1 (A), R47.2
unnamed: LED27.2 (C), Q1.3 (C)
unnamed: OSC1.3 (OUT), R27.1
unnamed: C15.1, L2.2, OSC1.4 (VDD)
unnamed: C4.1, U1.6 (BOOT)
unnamed: C8.2, R4.1, R5.2, U1.4 (FB)
unnamed: C4.2, L1.1, U1.2 (SW)
unnamed: R3.1, U2.6 (CFG)
unnamed: C1.2, R3.2, R67.2, U2.1 (VDD)
unnamed: R26.2, U11.9 (A8)
unnamed: L3.1, U13.3 (LX)
unnamed: R28.1, U15.7 (HOLD#RST#)
unnamed: R29.1, U15.3 (WP#)
unnamed: R34.2, U16.6 (CTS0/GPIO0/SCK/TCK)
unnamed: R33.2, U16.5 (DSR0/GPIO2/SCS0/TMS)
unnamed: R35.2, U16.7 (RTS0/GPIO1/MISO/TDO)
unnamed: R36.2, U16.8 (TXD0/MOSI/TDI)
unnamed: C44.1, U16.19 (XI), X2.1
unnamed: C45.1, U16.20 (XO), X2.2
VCC: C2.1, C3.1, R67.1, TP3.1 (1_1), U1.3 (VIN), USB1.A4B9 (VBUS), USB1.B4A9 (VBUS)
XTALI: C35.2, J2.25, R14.2, U8.36 (XTALI), X1.1 (OSC1)
XTALO: C36.1, J2.24, R14.1, U8.37 (XTALO), X1.2 (OSC2)
~ABORT: J1.20, U8.20 (~ABORT), U10.2 (A1)
~ABORT_L: U7.56 (IOB28A/GCLKT_5), U10.18 (B1)
~ALE: J2.21, U8.40 (~ALE), U11.3 (A2)
~ALE_L: U7.76 (IOB43B), U11.17 (B2)
~BUFCTL: J2.20, U8.41 (~BUFCTL), U11.2 (A1)
~BUFCTL_L: U7.75 (IOB42B), U11.18 (B1)
~DMR: J1.27, R11.2, U8.27 (~DMR)
~EVENT: J1.8, U8.8 (~EVENT), U11.7 (A6)
~EVENT_L: U7.81 (IOR22B), U11.13 (B6)
~FPE: J1.7, R9.2, U8.7 (~FPE)
~INIT: J2.28, R25.1, S2.1 (A), U8.33 (~INIT)
~MAP: J1.19, U8.19 (~MAP)
~MISS: J1.28, U8.28 (~MISS), U11.6 (A5)
~MISS_L: U7.80 (IOR24A), U11.14 (B5)
~PARITY: J1.14, R10.2, U8.14 (~PARITY)
~PRDC: J1.29, U8.29 (~PRDC)
~PWRF: J1.6, R8.2, U8.6 (~PWRF)
~SCTL: J2.23, U8.38 (~SCTL), U11.5 (A4)
~SCTL_L: U7.79 (IOR24B), U11.15 (B4)
~STRB: J2.22, U8.39 (~STRB), U11.4 (A3)
~STRB_L: U7.78 (IOB43A), U11.16 (B3)
~TEST1: J1.1, R7.2, U8.1 (~TEST1)
~TEST2: J2.30, R13.2, U8.31 (~TEST2)

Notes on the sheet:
FRONT PANEL LED
DCJ-11 Peripheral
POWER TREE
JTAG UART DEBUG USB
FPGA AND SRAM

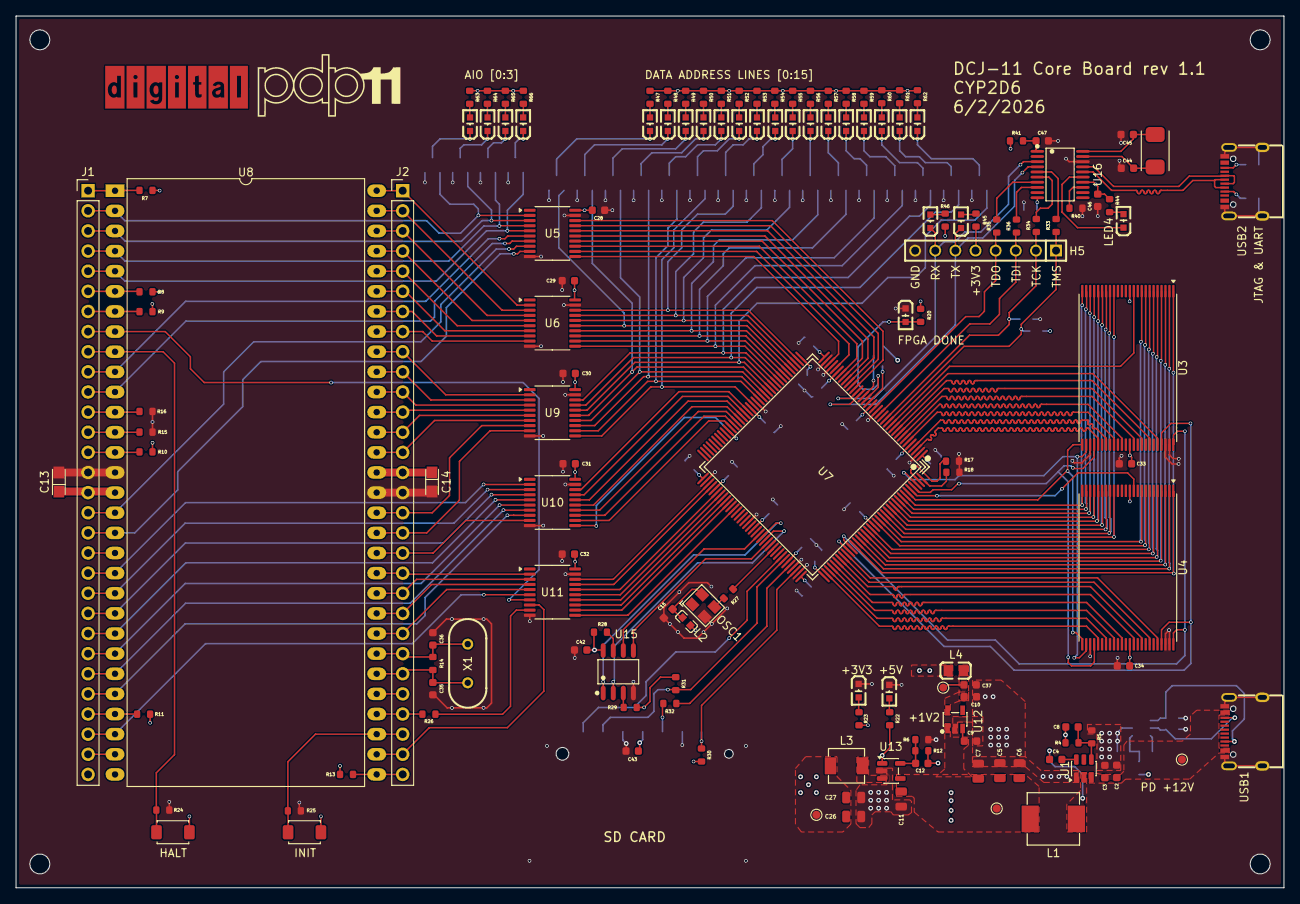
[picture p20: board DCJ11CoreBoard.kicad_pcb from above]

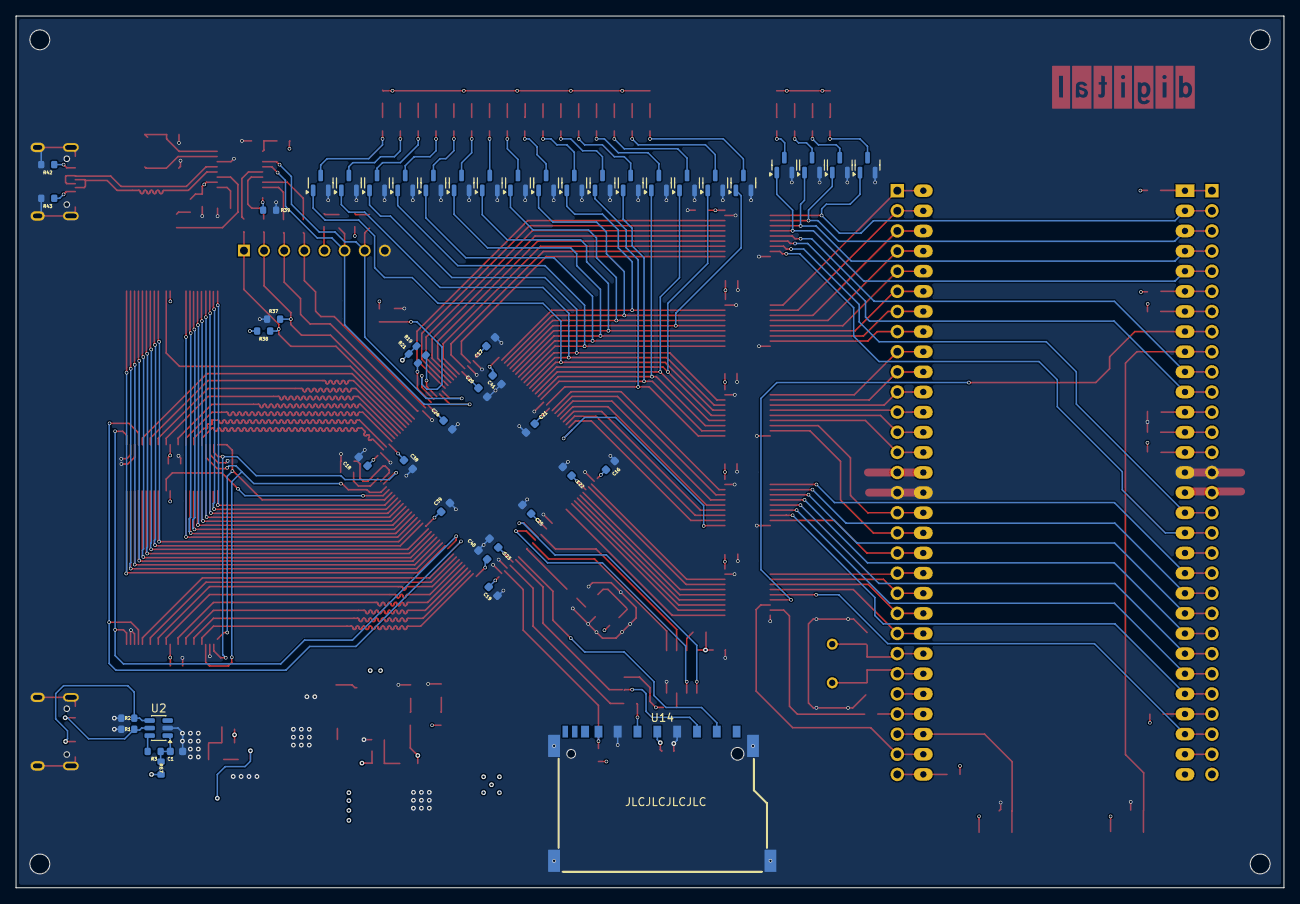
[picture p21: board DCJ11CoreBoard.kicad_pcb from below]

Board: 4 copper layers, 160.0 x 110.0 mm, 198 parts (48 on the bottom side), 236 nets.

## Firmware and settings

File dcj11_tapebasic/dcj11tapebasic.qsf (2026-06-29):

# -------------------------------------------------------------------------- #
#
# Copyright (C) 2018  Intel Corporation. All rights reserved.
# Your use of Intel Corporation's design tools, logic functions 
# and other software and tools, and its AMPP partner logic 
# functions, and any output files from any of the foregoing 
# (including device programming or simulation files), and any 
# associated documentation or information are expressly subject 
# to the terms and conditions of the Intel Program License 
# Subscription Agreement, the Intel Quartus Prime License Agreement,
# the Intel FPGA IP License Agreement, or other applicable license
# agreement, including, without limitation, that your use is for
# the sole purpose of programming logic devices manufactured by
# Intel and sold by Intel or its authorized distributors.  Please
# refer to the applicable agreement for further details.
#
# -------------------------------------------------------------------------- #
#
# Quartus Prime
# Version 18.1.0 Build 625 09/12/2018 SJ Standard Edition
# Date created = 15:35:22  June 28, 2026
#
# -------------------------------------------------------------------------- #
#
# Notes:
#
# 1) The default values for assignments are stored in the file:
#		dcj11tapebasic_assignment_defaults.qdf
#    If this file doesn't exist, see file:
#		assignment_defaults.qdf
#
# 2) Altera recommends that you do not modify this file. This
#    file is updated automatically by the Quartus Prime software
#    and any changes you make may be lost or overwritten.
#
# -------------------------------------------------------------------------- #


set_global_assignment -name FAMILY "Cyclone IV E"
set_global_assignment -name DEVICE EP4CE15F23C8
set_global_assignment -name TOP_LEVEL_ENTITY top
set_global_assignment -name ORIGINAL_QUARTUS_VERSION 18.1.0
set_global_assignment -name PROJECT_CREATION_TIME_DATE "15:35:22  JUNE 28, 2026"
set_global_assignment -name LAST_QUARTUS_VERSION "18.1.0 Standard Edition"
set_global_assignment -name PROJECT_OUTPUT_DIRECTORY output_files
set_global_assignment -name MIN_CORE_JUNCTION_TEMP 0
set_global_assignment -name MAX_CORE_JUNCTION_TEMP 85
set_global_assignment -name ERROR_CHECK_FREQUENCY_DIVISOR 1
set_global_assignment -name NOMINAL_CORE_SUPPLY_VOLTAGE 1.2V

set_location_assignment PIN_G21 -to clk50

set_location_assignment PIN_AB9 -to dcj_dal[0]
set_location_assignment PIN_AA15 -to dcj_dal[1]
set_location_assignment PIN_AB16 -to dcj_dal[2]
set_location_assignment PIN_AA16 -to dcj_dal[3]
set_location_assignment PIN_AB17 -to dcj_dal[4]
set_location_assignment PIN_AA17 -to dcj_dal[5]
set_location_assignment PIN_AA8 -to dcj_dal[6]
set_location_assignment PIN_AB8 -to dcj_dal[7]
set_location_assignment PIN_AA9 -to dcj_dal[8]
set_location_assignment PIN_AA10 -to dcj_dal[9]
set_location_assignment PIN_AB10 -to dcj_dal[10]
set_location_assignment PIN_AB13 -to dcj_dal[11]
set_location_assignment PIN_AA13 -to dcj_dal[12]
set_location_assignment PIN_AB14 -to dcj_dal[13]
set_location_assignment PIN_AA14 -to dcj_dal[14]
set_location_assignment PIN_AB15 -to dcj_dal[15]
set_location_assignment PIN_AA21 -to dcj_dal_hi[16]
set_location_assignment PIN_AA20 -to dcj_dal_hi[17]
set_location_assignment PIN_AB20 -to dcj_dal_hi[18]
set_location_assignment PIN_AA19 -to dcj_dal_hi[19]
set_location_assignment PIN_AB19 -to dcj_dal_hi[20]
set_location_assignment PIN_AA18 -to dcj_dal_hi[21]

set_location_assignment PIN_AA3 -to dcj_aio[0]
set_location_assignment PIN_AB3 -to dcj_aio[1]
set_location_assignment PIN_AA4 -to dcj_aio[2]
set_location_assignment PIN_AB4 -to dcj_aio[3]
set_location_assignment PIN_AA7 -to dcj_bs[0]
set_location_assignment PIN_AB7 -to dcj_bs[1]
set_location_assignment PIN_Y22 -to dcj_ale_n
set_location_assignment PIN_W22 -to dcj_sctl_n
set_location_assignment PIN_Y21 -to dcj_bufctl_n
set_location_assignment PIN_W21 -to dcj_strb_n
set_location_assignment PIN_U22 -to dcj_clk2
set_location_assignment PIN_W20 -to dcj_init_n
set_location_assignment PIN_U21 -to dcj_cont_n
set_location_assignment PIN_AA5 -to dcj_irq[0]
set_location_assignment PIN_AB5 -to dcj_irq[1]
set_location_assignment PIN_V22 -to dcj_event_n
set_location_assignment PIN_AB18 -to dcj_abort_n
set_location_assignment PIN_Y17 -to dcj_dv
set_location_assignment PIN_V21 -to dcj_miss_n

set_location_assignment PIN_B3 -to sram_addr[0]
set_location_assignment PIN_A3 -to sram_addr[1]
set_location_assignment PIN_B4 -to sram_addr[2]
set_location_assignment PIN_A4 -to sram_addr[3]
set_location_assignment PIN_B5 -to sram_addr[4]
set_location_assignment PIN_A5 -to sram_addr[5]
set_location_assignment PIN_B6 -to sram_addr[6]
set_location_assignment PIN_A6 -to sram_addr[7]
set_location_assignment PIN_A8 -to sram_addr[8]
set_location_assignment PIN_B9 -to sram_addr[9]
set_location_assignment PIN_A9 -to sram_addr[10]
set_location_assignment PIN_B10 -to sram_addr[11]
set_location_assignment PIN_A10 -to sram_addr[12]
set_location_assignment PIN_A13 -to sram_addr[13]
set_location_assignment PIN_B13 -to sram_addr[14]
set_location_assignment PIN_A14 -to sram_addr[15]
set_location_assignment PIN_B14 -to sram_addr[16]
set_location_assignment PIN_B7 -to sram_addr[17]
set_location_assignment PIN_A7 -to sram_addr[18]
set_location_assignment PIN_B8 -to sram_addr[19]
set_location_assignment PIN_C10 -to sram_addr[20]
set_location_assignment PIN_AA1 -to sram_dq_lo[0]
set_location_assignment PIN_Y2 -to sram_dq_lo[1]
set_location_assignment PIN_Y1 -to sram_dq_lo[2]
set_location_assignment PIN_W2 -to sram_dq_lo[3]
set_location_assignment PIN_W1 -to sram_dq_lo[4]
set_location_assignment PIN_V2 -to sram_dq_lo[5]
set_location_assignment PIN_V1 -to sram_dq_lo[6]
set_location_assignment PIN_U2 -to sram_dq_lo[7]
set_location_assignment PIN_A17 -to sram_dq_hi[0]
set_location_assignment PIN_B17 -to sram_dq_hi[1]
set_location_assignment PIN_A18 -to sram_dq_hi[2]
set_location_assignment PIN_B18 -to sram_dq_hi[3]
set_location_assignment PIN_A19 -to sram_dq_hi[4]
set_location_assignment PIN_B19 -to sram_dq_hi[5]
set_location_assignment PIN_A20 -to sram_dq_hi[6]
set_location_assignment PIN_B20 -to sram_dq_hi[7]
set_location_assignment PIN_B1 -to sram_ce1_n
set_location_assignment PIN_B2 -to sram_oe_n
set_location_assignment PIN_C4 -to sram_we_lo_n
set_location_assignment PIN_C3 -to sram_we_hi_n

set_location_assignment PIN_C1 -to uart_rx
set_location_assignment PIN_D2 -to uart_tx

set_location_assignment PIN_R22 -to sd_spi_sck
set_location_assignment PIN_P21 -to sd_spi_mosi
set_location_assignment PIN_R21 -to sd_spi_miso
set_location_assignment PIN_P22 -to sd_spi_cs_n
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

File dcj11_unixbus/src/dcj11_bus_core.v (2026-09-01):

`default_nettype none

module dcj11_bus_core #(
    parameter integer READ_SETUP_CYCLES = 3,
    parameter integer DV_RELEASE_CYCLES = 5,
    parameter integer ABORT_SETUP_CYCLES = 4,
    parameter integer ABORT_LED_CYCLES = 1000000
) (
    input  wire         clk,
    input  wire         reset_n,
    input  wire         enable,

    input  wire [21:0]  raw_address,
    input  wire [15:0]  raw_dal,
    input  wire [3:0]   raw_aio,
    input  wire [1:0]   raw_bs,
    input  wire         ale_n,
    input  wire         sctl_n,
    input  wire         strb_n,
    input  wire         bufctl_n,
    input  wire         dv_sense,
    input  wire         abort_sense_n,

    input  wire         peripheral_hit,
    input  wire [15:0]  peripheral_data,
    output wire [21:0]  peripheral_address,
    output reg  [21:0]  peripheral_read_address,
    output reg  [21:0]  peripheral_write_address,
    output reg          peripheral_read_pulse,
    output reg          peripheral_write_pulse,
    output reg  [15:0]  peripheral_write_data,
    output reg  [1:0]   peripheral_byte_enable,

    input  wire [1:0]   interrupt_requests,
    input  wire [15:0]  interrupt_vector0,
    input  wire [15:0]  interrupt_vector1,
    output reg  [1:0]   interrupt_ack,
    output reg  [15:0]  interrupt_ack_vector,
    output reg          event_ack,
    output reg          bus_reset,

    output reg          cpu_mem_request_valid,
    input  wire         cpu_mem_request_ready,
    output reg          cpu_mem_request_write,
    output reg  [21:0]  cpu_mem_request_address,
    output reg  [15:0]  cpu_mem_request_data,
    output reg  [1:0]   cpu_mem_request_byte_enable,
    input  wire         cpu_mem_response_valid,
    input  wire [15:0]  cpu_mem_response_data,
    input  wire         cpu_mem_response_error,
    output wire         cpu_rmw_lock,

    output wire [15:0]  dal_out,
    output wire         dal_oe,
    output wire         cont_n,
    output wire         abort_n,
    output wire         dv_drive_low,
    output wire         miss_drive_low,
    output wire         abort_led_n,
    output reg          odt_seen,
    output reg  [21:0]  last_address,
    output reg  [15:0]  last_data,
    output reg  [3:0]   last_aio
);
    localparam [3:0] AIO_NIO        = 4'b1111;
    localparam [3:0] AIO_GP_READ    = 4'b1110;
    localparam [3:0] AIO_INTACK     = 4'b1101;
    localparam [3:0] AIO_RMW_LOCKED = 4'b1010;
    localparam [3:0] AIO_ODT_READ   = 4'b0110;
    localparam [3:0] AIO_GP_WRITE   = 4'b0101;
    localparam [3:0] AIO_BYTE_WRITE = 4'b0011;
    localparam [3:0] AIO_WORD_WRITE = 4'b0001;
    localparam [21:0] IO_PAGE_BASE  = 22'o17760000;
    localparam [15:0] POWER_UP_WORD = 16'o000003;

    localparam [3:0] ST_IDLE          = 4'd0;
    localparam [3:0] ST_DECODE        = 4'd1;
    localparam [3:0] ST_MEM_REQUEST   = 4'd2;
    localparam [3:0] ST_MEM_RESPONSE  = 4'd3;
    localparam [3:0] ST_WAIT_SCTL     = 4'd4;
    localparam [3:0] ST_COMMIT_WRITE  = 4'd5;
    localparam [3:0] ST_DATA_SETUP    = 4'd6;
    localparam [3:0] ST_DV_HOLD_LOW   = 4'd7;
    localparam [3:0] ST_DV_VALID      = 4'd8;
    localparam [3:0] ST_RESPOND       = 4'd9;
    localparam [3:0] ST_ABORT         = 4'd10;
    localparam [3:0] ST_RETIRE        = 4'd11;
    localparam [3:0] ST_ABORT_SETUP   = 4'd12;

    function is_read_aio;
        input [3:0] aio;
        begin
            is_read_aio = (((aio[3] == 1'b1) && (aio != AIO_NIO)) ||
                           (aio == AIO_ODT_READ));
        end
    endfunction

    function is_write_aio;
        input [3:0] aio;
        begin
            is_write_aio = (aio == AIO_GP_WRITE) ||
                           (aio == AIO_BYTE_WRITE) ||
                           (aio == AIO_WORD_WRITE);
        end
    endfunction

    function [1:0] byte_lanes;
        input [3:0] aio;
        input       address_bit_zero;
        begin
            if (aio == AIO_BYTE_WRITE)
                byte_lanes = address_bit_zero ? 2'b10 : 2'b01;
            else
                byte_lanes = 2'b11;
        end
    endfunction

    reg [21:0] ale_address;
    reg [15:0] ale_dal;
    reg [3:0]  ale_aio;
    reg [1:0]  ale_bs;
    reg        ale_latched_valid;
    reg        ale_capture_toggle;
    reg        ale_started_idle;
    reg        ale_started_before_completion;
    reg        ale_cpu_abort;
    reg [15:0] sctl_write_data;

    reg [3:0]  state;
    reg        transaction_owned;
    reg        transaction_completion_issued;

    always @(negedge ale_n or negedge reset_n) begin
        if (!reset_n) begin
            ale_address <= 22'd0;
            ale_dal <= 16'd0;
            ale_aio <= AIO_NIO;
            ale_bs <= 2'b00;
            ale_latched_valid <= 1'b0;
            ale_capture_toggle <= 1'b0;
            ale_started_idle <= 1'b1;
            ale_started_before_completion <= 1'b0;
            ale_cpu_abort <= 1'b0;
        end else begin
            ale_address <= raw_address;
            ale_dal <= raw_dal;
            ale_aio <= raw_aio;
            ale_bs <= raw_bs;
            ale_latched_valid <= 1'b1;
            ale_capture_toggle <= ~ale_capture_toggle;
            ale_started_idle <= sctl_n && strb_n;
            ale_started_before_completion <= transaction_owned &&
                !transaction_completion_issued;
            ale_cpu_abort <= !abort_sense_n;
        end
    end

    always @(negedge sctl_n or negedge reset_n) begin
        if (!reset_n)
            sctl_write_data <= 16'd0;
        else
            sctl_write_data <= raw_dal;
    end

    (* async_reg = "true", altera_attribute = "-name SYNCHRONIZER_IDENTIFICATION FORCED_IF_ASYNCHRONOUS" *)
    reg ale_capture_meta;
    (* async_reg = "true", altera_attribute = "-name SYNCHRONIZER_IDENTIFICATION FORCED_IF_ASYNCHRONOUS" *)
    reg ale_capture_sync;
    reg ale_capture_seen;
    (* async_reg = "true", altera_attribute = "-name SYNCHRONIZER_IDENTIFICATION FORCED_IF_ASYNCHRONOUS" *)
    reg sctl_meta;
    (* async_reg = "true", altera_attribute = "-name SYNCHRONIZER_IDENTIFICATION FORCED_IF_ASYNCHRONOUS" *)
    reg sctl_sync;
    reg sctl_previous;
    (* async_reg = "true", altera_attribute = "-name SYNCHRONIZER_IDENTIFICATION FORCED_IF_ASYNCHRONOUS" *)
    reg strb_meta;
    (* async_reg = "true", altera_attribute = "-name SYNCHRONIZER_IDENTIFICATION FORCED_IF_ASYNCHRONOUS" *)
    reg strb_sync;
    (* async_reg = "true", altera_attribute = "-name SYNCHRONIZER_IDENTIFICATION FORCED_IF_ASYNCHRONOUS" *)
    reg bufctl_meta;
    (* async_reg = "true", altera_attribute = "-name SYNCHRONIZER_IDENTIFICATION FORCED_IF_ASYNCHRONOUS" *)
    reg bufctl_sync;
    (* async_reg = "true", altera_attribute = "-name SYNCHRONIZER_IDENTIFICATION FORCED_IF_ASYNCHRONOUS" *)
    reg dv_meta;
    (* async_reg = "true", altera_attribute = "-name SYNCHRONIZER_IDENTIFICATION FORCED_IF_ASYNCHRONOUS" *)
    reg dv_sync;
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

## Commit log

2026-05-23 first version PCB implementation
    [DCJ11CoreBoard-CuBottom.gbr, DCJ11CoreBoard-CuIn1.gbr, DCJ11CoreBoard-CuIn2.gbr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]
2026-06-06 update hardware design rev 1.1
    [DCJ11CoreBoard-CuBottom.gbr, DCJ11CoreBoard-CuIn1.gbr, DCJ11CoreBoard-CuIn2.gbr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]
2026-06-23 update hardware design rev 1.2
    [DCJ11CoreBoard-CuBottom.gbr, DCJ11CoreBoard-CuIn1.gbr, DCJ11CoreBoard-CuIn2.gbr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]
2026-06-24 add status led and aw21024 front panel led controller test hdl
2026-06-24 add uart test hdl
2026-06-24 modify the value of PD negotiation chip's cfg resistor
    [DCJ11CoreBoard_v1.2-CuBottom.gbr, DCJ11CoreBoard_v1.2-CuIn1.gbr, DCJ11CoreBoard_v1.2-CuIn2.gbr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]
2026-06-26 add README for hardware rev 1.2 and initial system bring-up project for DCJ-11 CPU
    [dcj11_helloworld.smp_dump.txt, stp1.stp, stp1_auto_stripped.stp]
2026-06-26 remove build artifacts and intermediate compilation products
    [dcj11_helloworld.smp_dump.txt, stp1_auto_stripped.stp]
2026-06-29 add paper tape basic for dcj-11 project
    [DCJ11CoreBoard_v1.2-CuBottom.gbr, DCJ11CoreBoard_v1.2-CuIn1.gbr, DCJ11CoreBoard_v1.2-CuIn2.gbr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]
2026-07-29 update hardware design rev 1.3
    [DCJ11CoreBoard_v1.2-CuBottom.gbr, DCJ11CoreBoard_v1.2-CuIn1.gbr, DCJ11CoreBoard_v1.2-CuIn2.gbr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]
2026-09-01 add 2.11 BSD Unix bus project
    [stp2.stp]
